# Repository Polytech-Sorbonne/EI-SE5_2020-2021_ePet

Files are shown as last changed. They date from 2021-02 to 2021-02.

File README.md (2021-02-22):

# Projet IOT : ePet

Projet réalisé dans le cadre de l'UE de "Projet IOT" , réalisé par 4 élèves ingénieurs de Polytech Sorbonne. Ce sujet a été proposé par Mme CHOTIN.

Le projet consiste en un collier connecté pour animal de compagnie, permettant de suivre sa position et d'avoir des informations pertinentes de son activité, notamment sa localisation, détecter s'il est sorti du périmètre de sécurité instauré par son maître. Le collier est équipé d'une ESP32 qui récupère également la température de l'animal afin de vérifier son état de santé.

## Comment obtient-on ces différentes informations :
 - Les données sont envoyées via Sigfox à notre serveur local hébergé sur une Raspberry Pi.  
 - Les déplacements sont détectés via un accéléromètre et les températures via un thermomètre.
 - La localisation est obtenue à partir des réseaux WIFI détectés à proximité de l'ESP32. On récupère les deux réseaux WIFI avec un signal le plus puissant et on envoie les informations à l'API Google qui nous renvoie la géolocalisation de l'animal.
 - Le maître peut visualiser ces données via le site mis en place hébergé par le serveur.

## Serveur :

Pour la partie serveur, toutes les informations se trouvent dans la partie CLOUD. Il y a également un tutoriel pour configurer une box et une raspberry pi afin d'héberger un site web.

## Electronique :

Pour la partie électronique, le matériel utilisé est renseigné dans le fichier Liste_du_matériels_finale.pdf . On obtient le système ci-dessous:

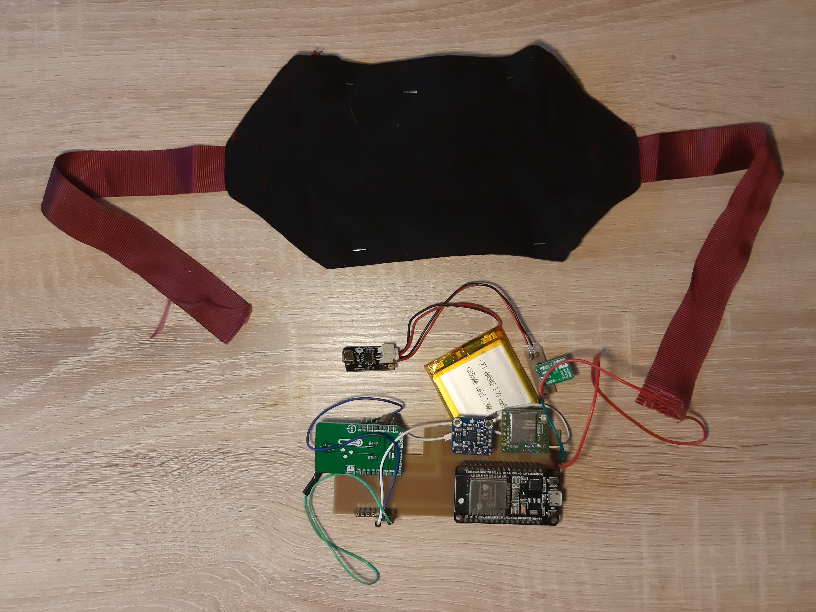
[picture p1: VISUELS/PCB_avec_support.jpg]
Electronique
    

Dans cette partie, vous trouverez également :
####
 * les codes arduino pour ESP32 (voir BLE/ et CODE/)
 * les différentes adresses MAC à exclure pour la détection des adresses MAC des WIFI
 * les schémas des PCB ainsi que les fichiers des traçages et de perçage.
 * les schémas électroniques pour effectuer les branchements des capteurs sur une plaque LABDEC  

## Fonctionnement du site :

Pour visualiser les différentes données envoyées par l'antenne Sigfox, nous avons réalisé un site. Ce site est constitué de plusieurs pages HTML.

### Identification :

Lorsque qu'un utilisateur veut consulter son compte utilisateur, il doit obligatoirement renseigner son identifiant ainsi que son mot de passe pour se connecter.

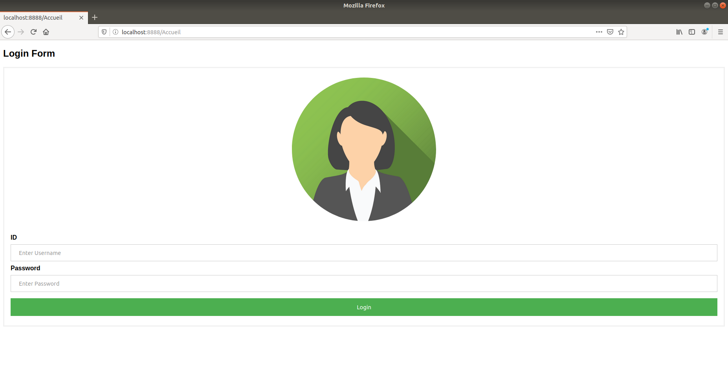
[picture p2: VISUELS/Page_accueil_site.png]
Site Identification


### Espace utilisateur :

Cet espace permet à l'utilisateur de sélectionner l'information qui veut consulter. Il peut donc accéder soit à la localisation soit à la température de ces animaux de compagnie. Il peut également consulter le code source disponible sur ce Github.

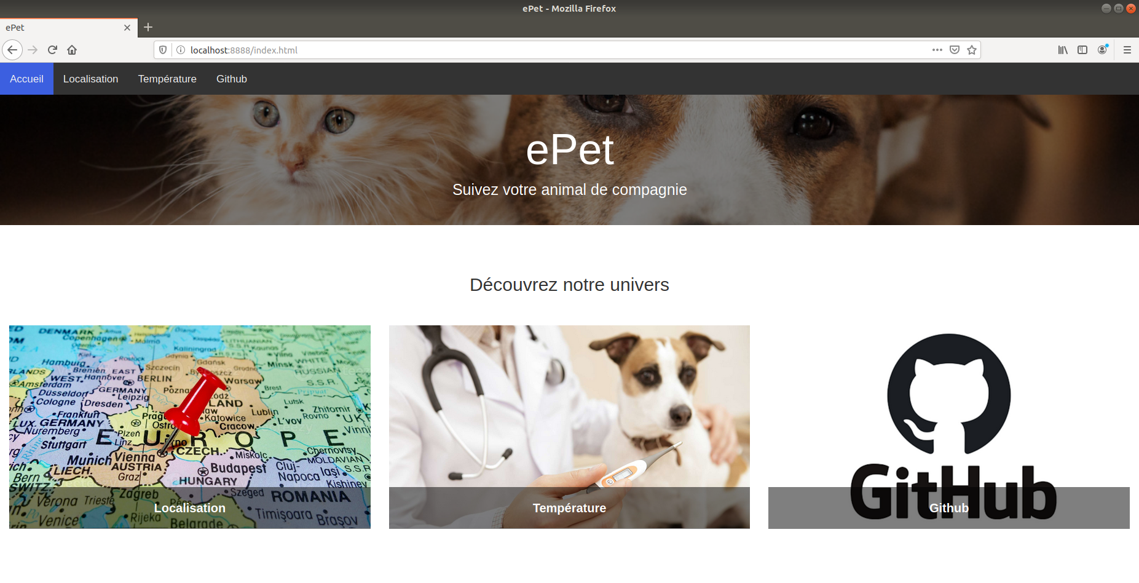
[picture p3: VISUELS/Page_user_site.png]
Site Espace Utilisateur


### Localisation :

Dans cette page, on peut choisir l'animal pour lequel on veut consulter sa position. Lorsque l'animal est en dehors du périmètre défini, un message s'affiche.

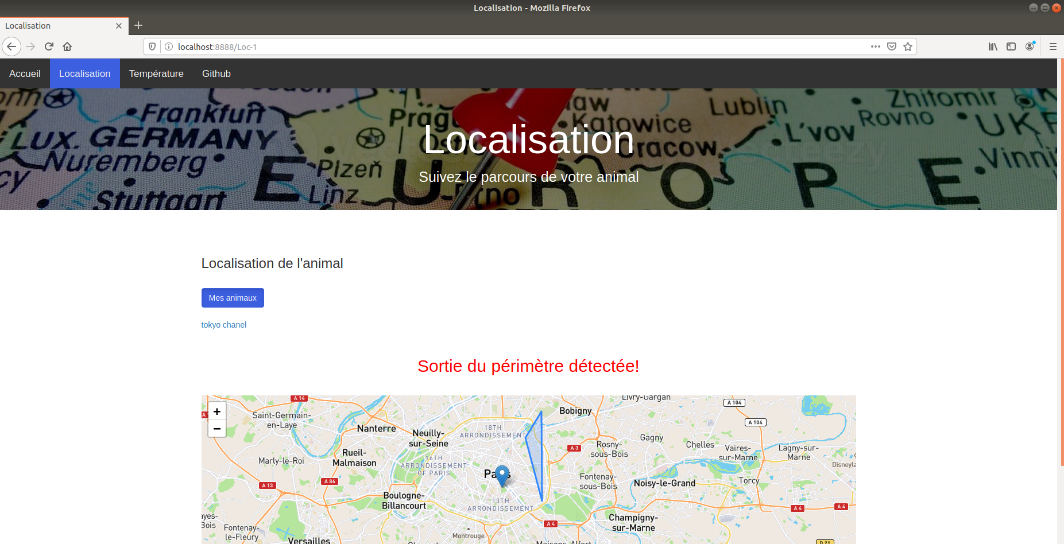
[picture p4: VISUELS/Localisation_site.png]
Site Localisation


### Température :  

Pour la température, on peut consulter la température de son animal grâce à un tableau. La température s'affiche seulement dans le cas où la température est anormale.

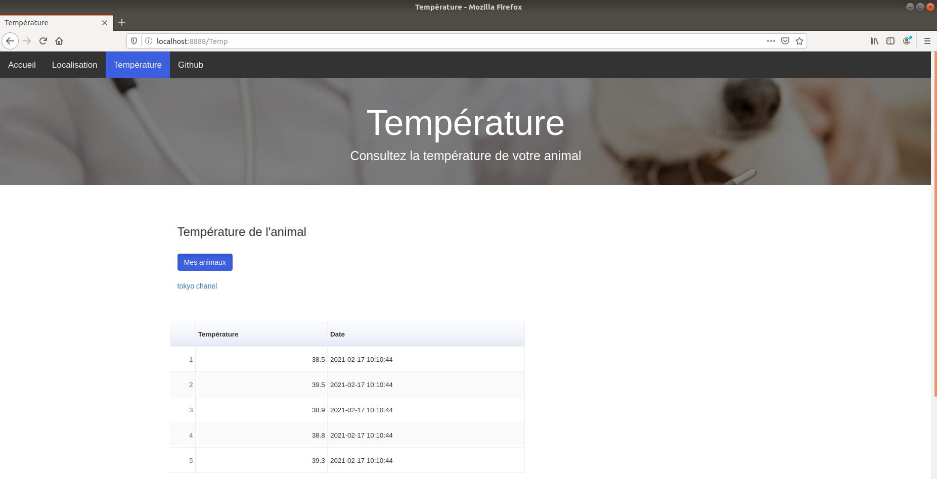
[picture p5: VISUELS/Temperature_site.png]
Site Température


### Vidéo:
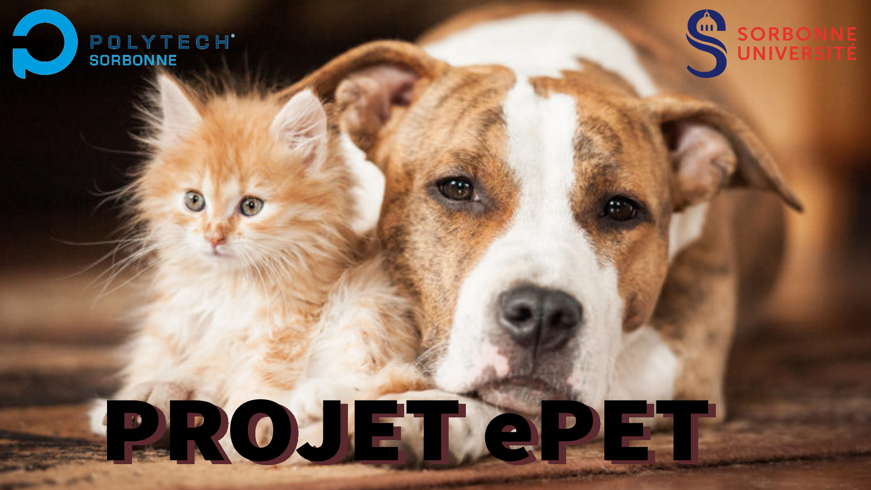
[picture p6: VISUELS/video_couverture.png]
Vidéo présentation

Consultez notre vidéo de présentation au lien suivant: https://youtu.be/6R1KARqUVJA

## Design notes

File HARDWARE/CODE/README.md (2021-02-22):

# Code Arduino 
Les dossiers contenus ici contiennent le code arduino compatible à l'esp32. Les librairies de l'accéléromètre MMA8451, et du capteur de temperature SHTC3 doivent être ajoutées aux codes correspondant et pour le schema complet. 

## Schéma complet
Explication du code:
Toutes les NB_SECOND = 60 , une interruption a lieu.
Cette interruption est rattachée à la tâche task1: elle permet de déterminer quand on doit stocker les données associées à l'accéléromètre et celles associées au capteur de température via deux compteurs : minutes_acc et totalInterruptCounter.

Au bout de 7 minutes, une moyenne des temperatures relevées est faite et stockée dans temp1 et temp2.

Pendant 15 minutes, des données d'activité sont déterminées en comparant la différence d'accélération sur les axes X et Y à un seuil de valeur seuilX et seuilY: si la différence est minime, on considère que l'activité n'est pas considérable. 

Sinon on le stocke dans mouvX ou mouvY et on incrémente un compteur countX ou countY suivant l'axe. 

Finalement, au bout de 15 minutes dans la loop principale, on scanne les wifis environnantes, on vérifie que ce ne sont pas les mêmes que l'on a déjà transmises au serveur, on élimine celles qui sont signes d'un constructeur mobile (en les comparant les 3 premiers octets avec ceux du tableau mac) et on forme le message Sigfox à envoyer au serveur. 

Ce message se forme en testant si la température est en dehors d'une plage de valeur typique d'une température normale d'un animal de compagnie (37-38 °C +- sensibilité_capteur), et si l'animal à bougé de façon significative (countX + countY > Xaddseuil + Yaddseuil). 

Ainsi, selon le cas, la trame formée et envoyée sera différente (voir doc SITE pour le décodage)

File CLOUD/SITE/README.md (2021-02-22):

# Serveur correspondant au site de visualisation des données

## Base de données
Le serveur est rattaché à une base de données epet.db, mise à jour à chaque réception de données.

## Récupération des données
Les données sont récupérées depuis le backend de sigfox via un POST sur /device.
Elles sont envoyées sous format JSON et contiennent :
- l'id du device Sigfox émetteur,
- la trame reçue
- le timestamp associé

Pour pouvoir recevoir les callbacks depuis le backend de Sigfox, il faut lancer le serveur en public. Dans le cadre de notre projet nous l'avons hébergé sur une Raspberry Pi.

Les fichiers contenus dans example_requests permettent de simuler un callback sigfox pour plusieurs trames.
	
## Localisation et requêtes Google API
La localisation est déterminée par la technique de sniffing de wifi, avec 2 adresses mac environnant le device et leur rssi, on peut interroger des bases telles que celle de Google, et recevoir une localisation. Pour se faire, il faut enregistrer un compte sur Google Api, créer un profil de paiement, et récupérer une clé API.
Notre clé API Google a été stockée dans le fichier key2.txt .

Le fichier Geoloc_example.py permet de récupérer les adresses mac et leur rssi depuis deux trames tests, puis d'interroger google API et récupérer le couple (lat,long) dans la réponse.

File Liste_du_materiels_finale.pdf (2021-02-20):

| | | | | | | Liens
Dénomination | Référence constructeur | Code commande | Quantité | Fournisseur | Lien URL | Montant TTC | Gotronic : https://www.gotronic.fr/
Module Sigfox Wisol | BRKWS01 | | 1 | | | | Farnell : https://fr.farnell.com/
Accéléromètre (I2C) | Accéléromètre 3 axes MMA8451, code : 33246 | | 1 | GoTronic | https://www.gotronic.fr/art-accelerometre-3-axes-mma8451-22164.htm 9,65 | | RS Components : https://fr.rs-online.com/web/
Microcontrôleur ESP32 | 35989 | | 1 | GoTronic | https://www.gotronic.fr/art-module-nodemcu-esp32-28407.htm 12
Batterie | Li-Ion Battery 3,7V 1050 mAh | | 1 | GoTronic | https://www.gotronic.fr/art-accu-li-ion-3-7-v-1050-mah-pr474446-5811.htm#complte_desc 10,9
Lipo Rider | Chargeur LiPo Micro-USB DFR0667, code: 36974 | | 1 | GoTronic | https://www.gotronic.fr/art-chargeur-lipo-micro-usb-dfr0667-32439.htm 6,3
Régulateur 3,3V | Régulateur 3,3 V S7V8F3 | | 1 | GoTronic | https://www.gotronic.fr/art-regulateur-3-3-v-s7v8f3-21747.htm 6,2
Capteur de température | Carte Click 9 Temp et Hum, capteur de température/humidité SHTC3 | | 1 | Farnell | https://fr.farnell.com/mikroelektronika/mikroe-3331/carte-click-temperature-humidite/dp/3013737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 12,74
| | | | | Total | 57,79

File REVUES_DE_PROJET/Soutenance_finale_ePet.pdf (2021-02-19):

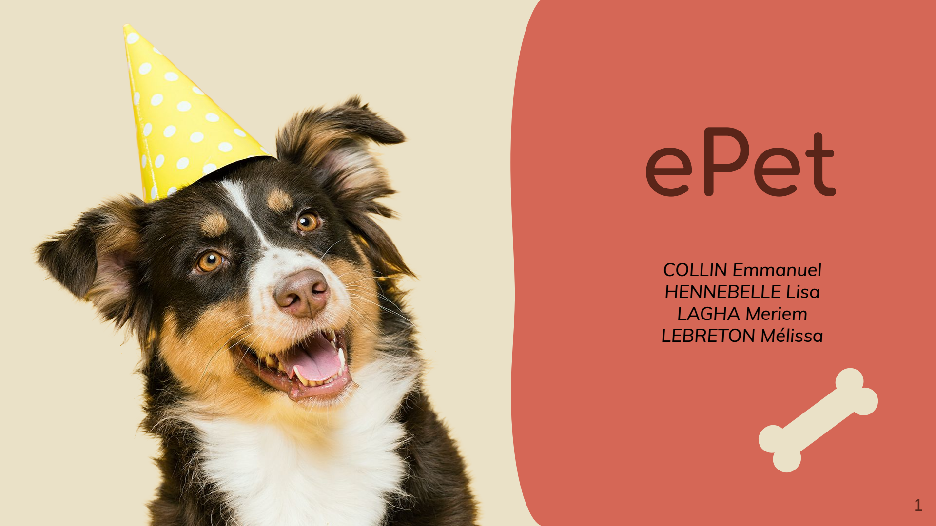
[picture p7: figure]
ePet; COLLIN Emmanuel HENNEBELLE Lisa LAGHA Meriem LEBRETON Mélissa

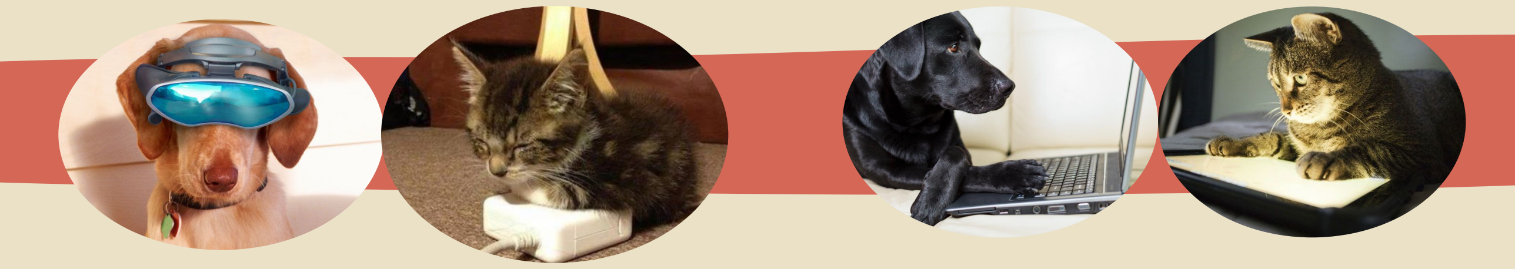
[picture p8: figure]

COLLIN Emmanuel, HENNEBELLE Lisa, LAGHA Meriem, LEBRETON Mélissa - Projet IoT : ePet

# Présentation de l’équipe et des rôles

## Lisa -Equipe Hardware-

## Emmanuel -Equipe Software-

## Meriem -Equipe Software-

## Mélissa -Equipe Hardware-

# Contexte

# Applications existantes :

# Incomplètes

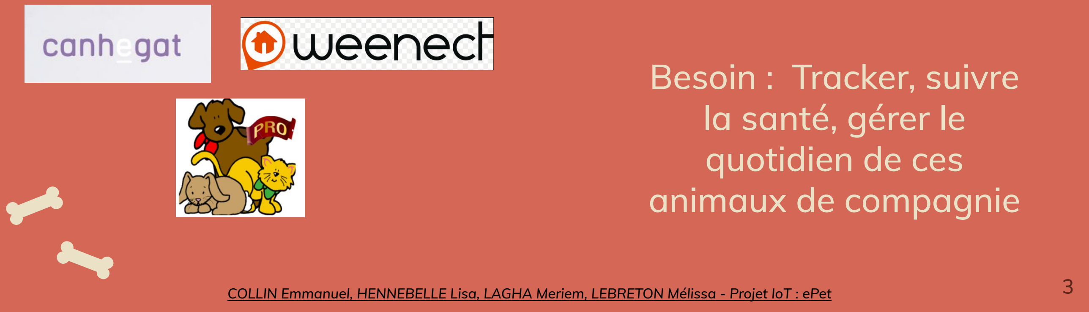
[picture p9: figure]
Besoin : Tracker, suivre la santé, gérer le quotidien de ces animaux de compagnie

# Table oÿ Contents

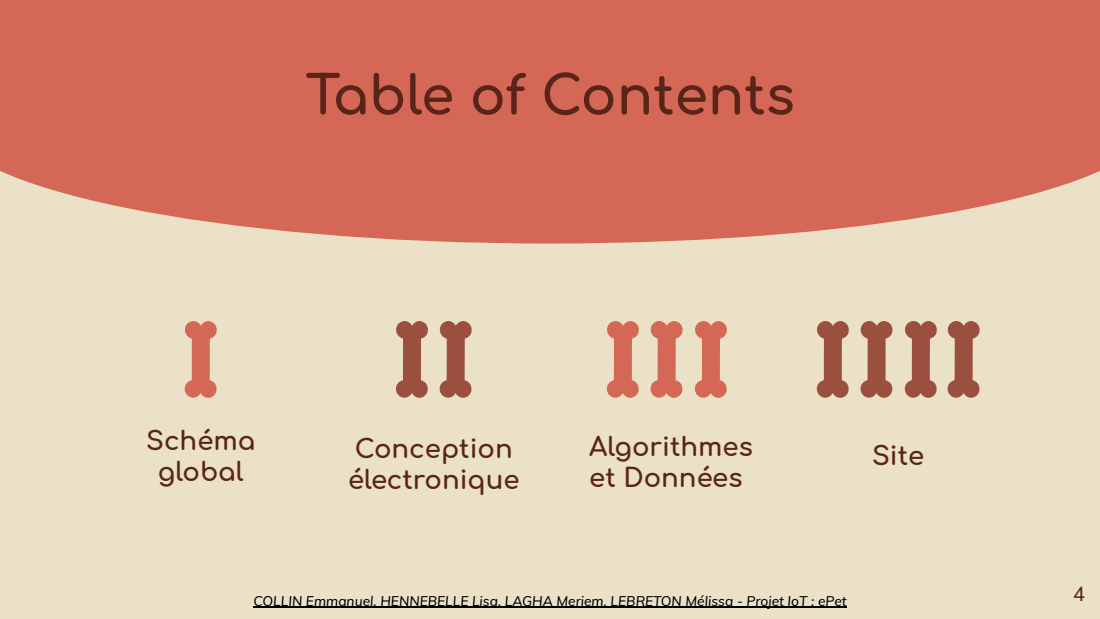
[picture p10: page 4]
Conception électronique; Alorithmes et Données; Schéma; lobal; Site

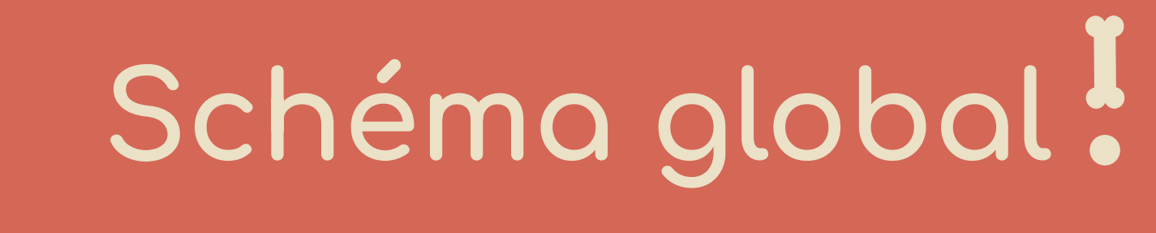
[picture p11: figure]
Schéma lobal

HARDWARE | SOFTWARE

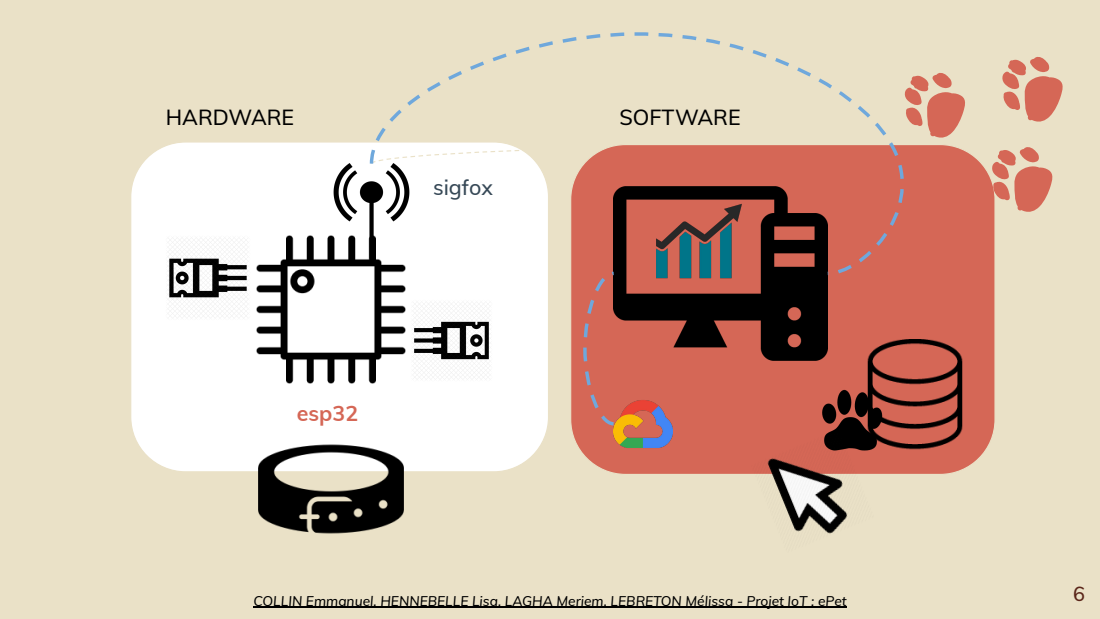
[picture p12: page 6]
esp32; sigfox

# Conception

# électronique

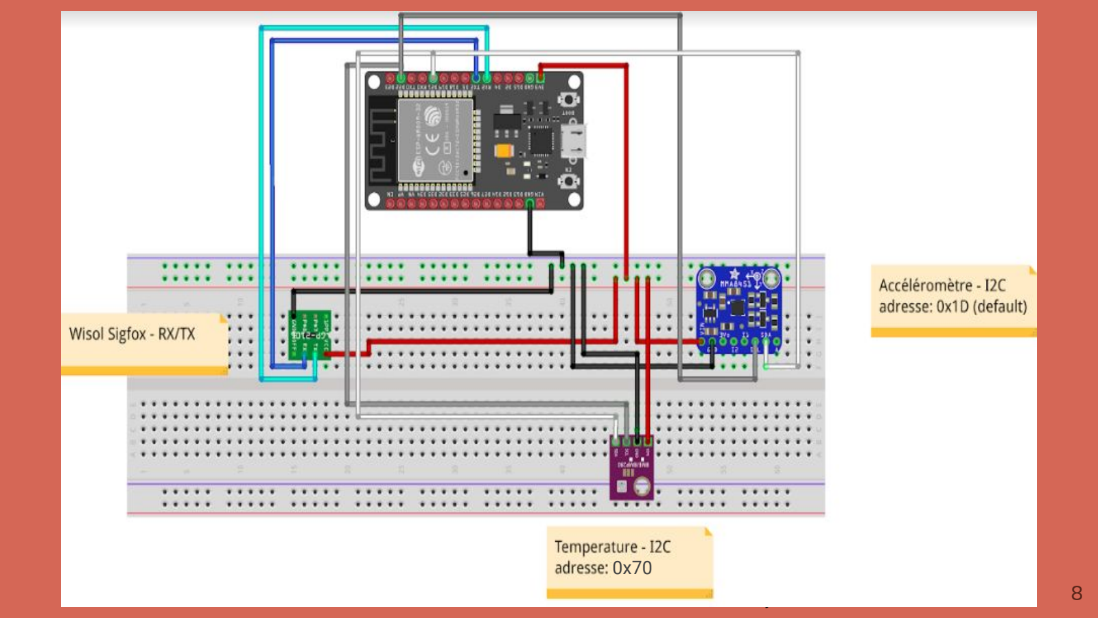
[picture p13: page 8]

0x70

# PCB d’alimentation

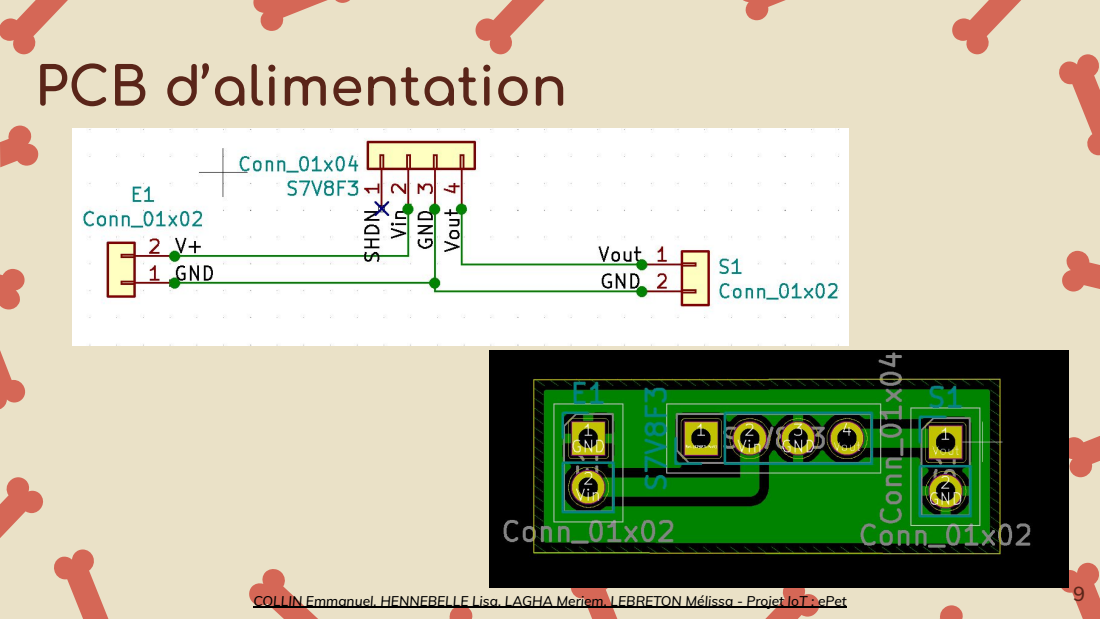
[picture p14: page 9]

# PCB des capteurs

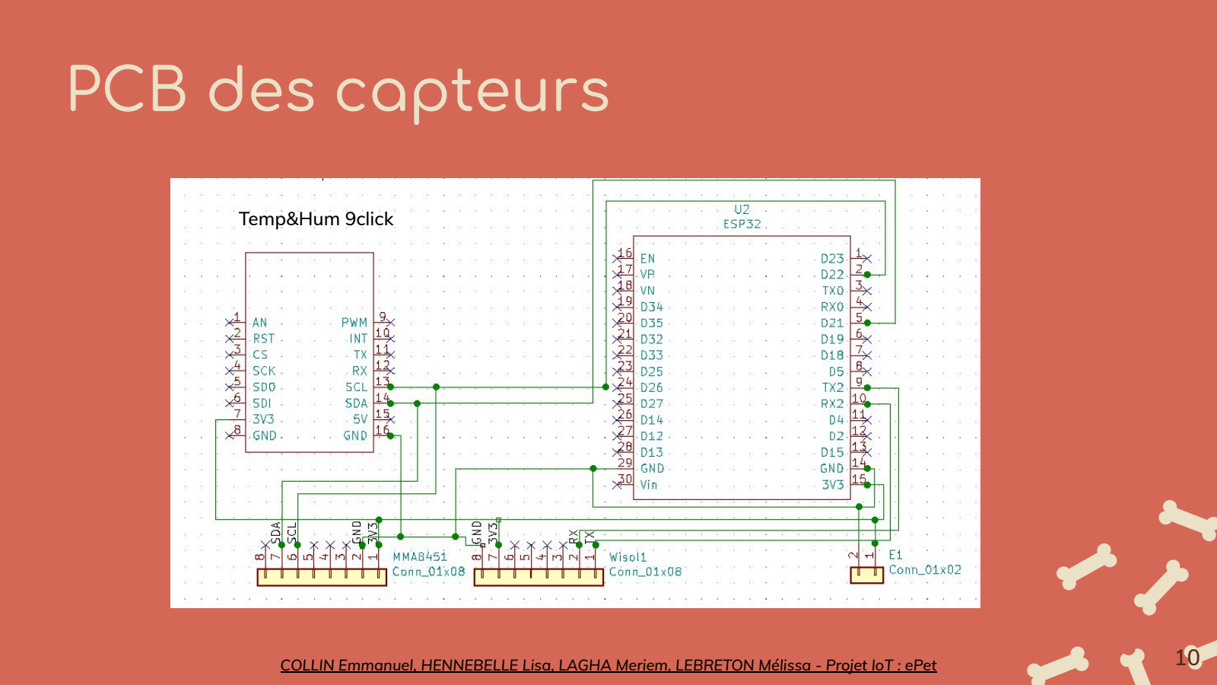
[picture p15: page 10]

COLLIN Emmanuel, HENNEBELLE Lisa, LAGHA Meriem, LEBRETON Mélissa - Projet IoT : ePet | 10

### Temp&Hum 9click

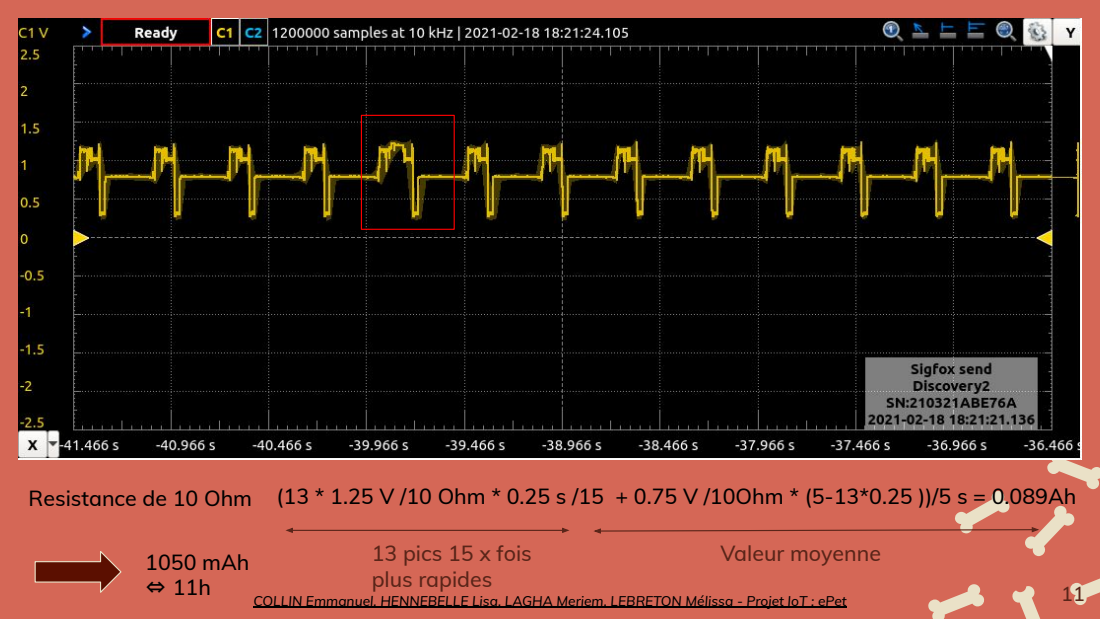
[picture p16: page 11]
COLLIN Emmanuel, HENNEBELLE Lisa, LAGHA Meriem, LEBRETON Mélissa - Projet IoT : ePet; Resistance de 10 Ohm; (13 * 1.25 V /10 Ohm * 0.25 s /15 + 0.75 V /10Ohm * (5-13*0.25 ))/5 s = 0.089Ah; 13 pics 15 x fois plus rapides

Valeur moyenne 1050 mAh

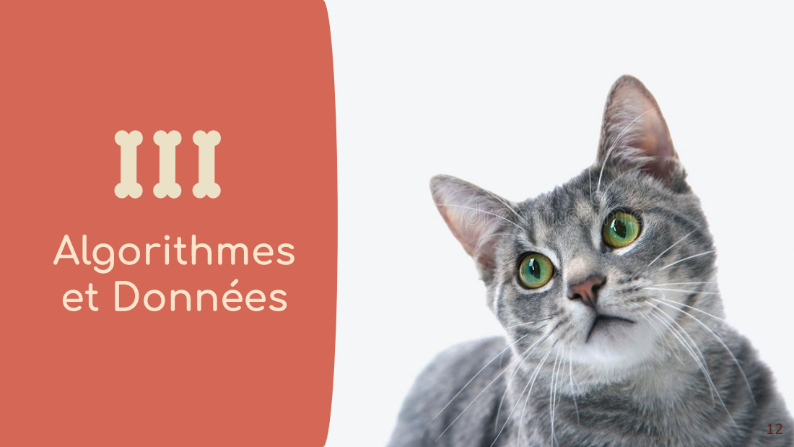
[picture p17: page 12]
Alorithmes et Données

# Algorithme

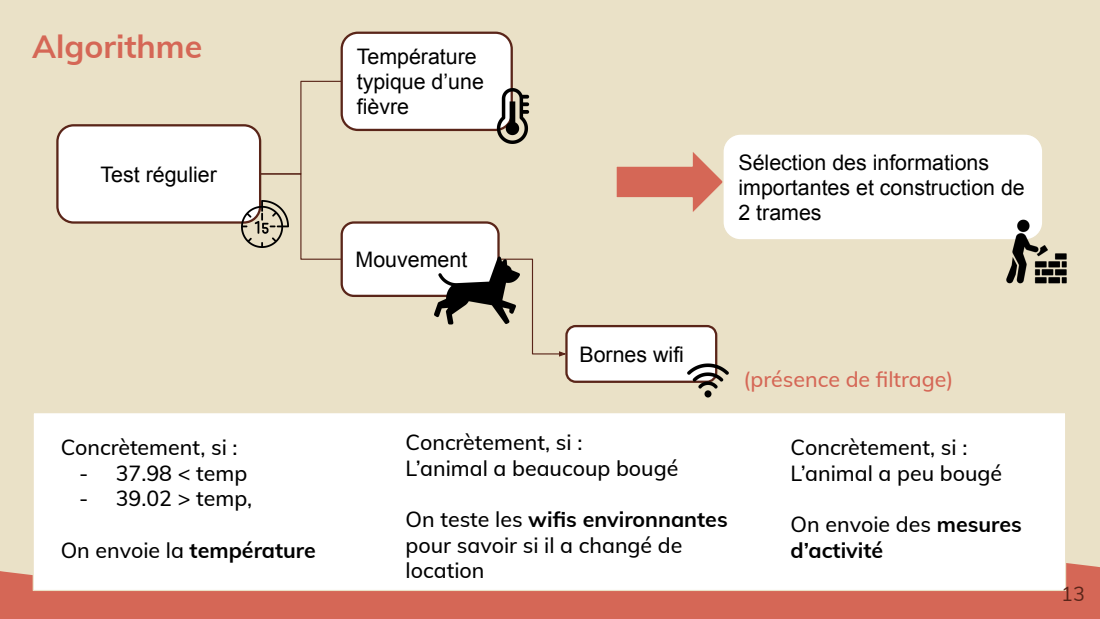
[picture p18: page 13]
Test régulier; Température typique d’une fièvre; Mouvement; Concrètement, si : - 37.98 < temp - 39.02 > temp,; Bornes wifi

Sélection des informations
importantes et construction de
2 trames

(présence de filtrage)

Concrètement, si :
L’animal a beaucoup bougé

L’animal a peu bougé

On teste les wifis environnantes
pour savoir si il a changé de
location

On envoie des mesures
d’activité

On envoie la température

XX | 0X
6 octets | 1 octet | 2 octets | 2 octets

trame de 10 octets (10*8 bits) maximum
| RSSI
| | XX | XX
XX | | XX | | XX | XX | XX | XX | XX

(puissance
du signal) BSSID (@ MAC) ou mouvX ou mouvY | temp (°C)

XX

1 octet

loc_mode

Tempér ature | mouvement X & Y | BSSID + RSSI | valeur de loc_mode associé
Cas 0 | NON | NON | - | Pas d’envoi
Cas 1 | OUI | NON | - | 06
Cas 2 | NON | OUI | NON | 01(X) ou 02(Y)
Cas 3 | OUI | OUI | NON | 04(X) ou 05(Y)
Cas 4 | NON | OUI | OUI | 00
Cas 5 | OUI | OUI | OUI

# Callback Sigfox

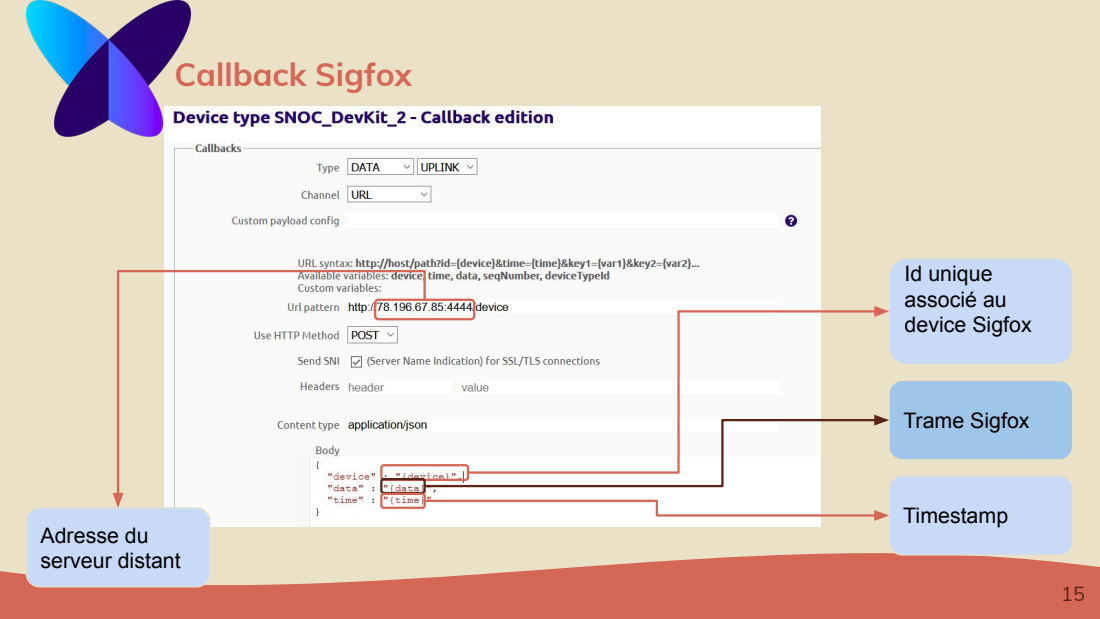
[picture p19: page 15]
Adresse du serveur distant; Id unique associé au device Sigfox; Trame Sigfox; Timestamp

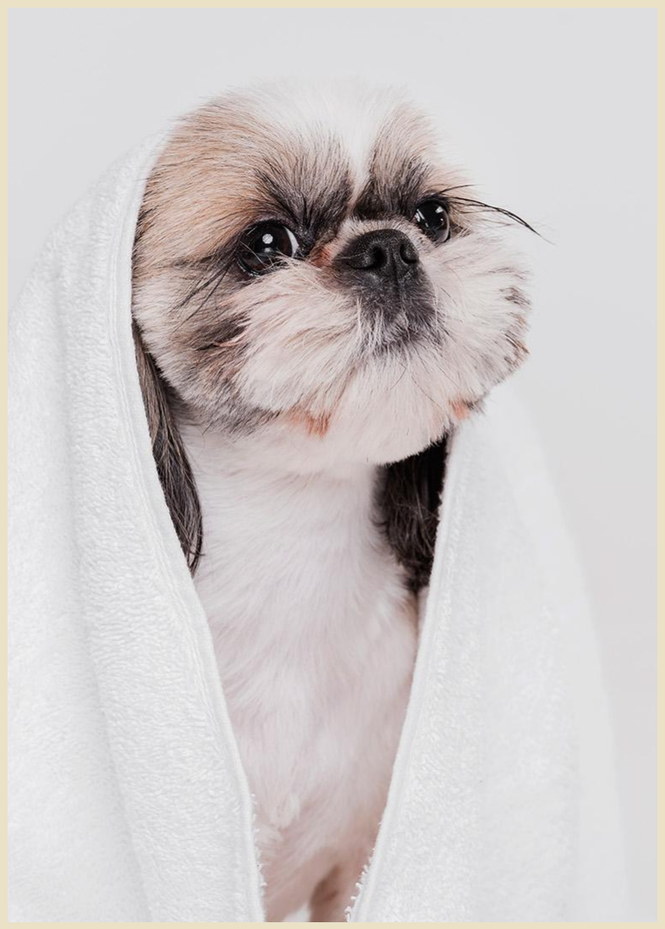
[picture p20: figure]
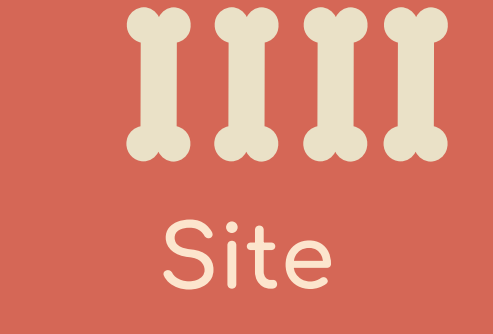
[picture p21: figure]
Site
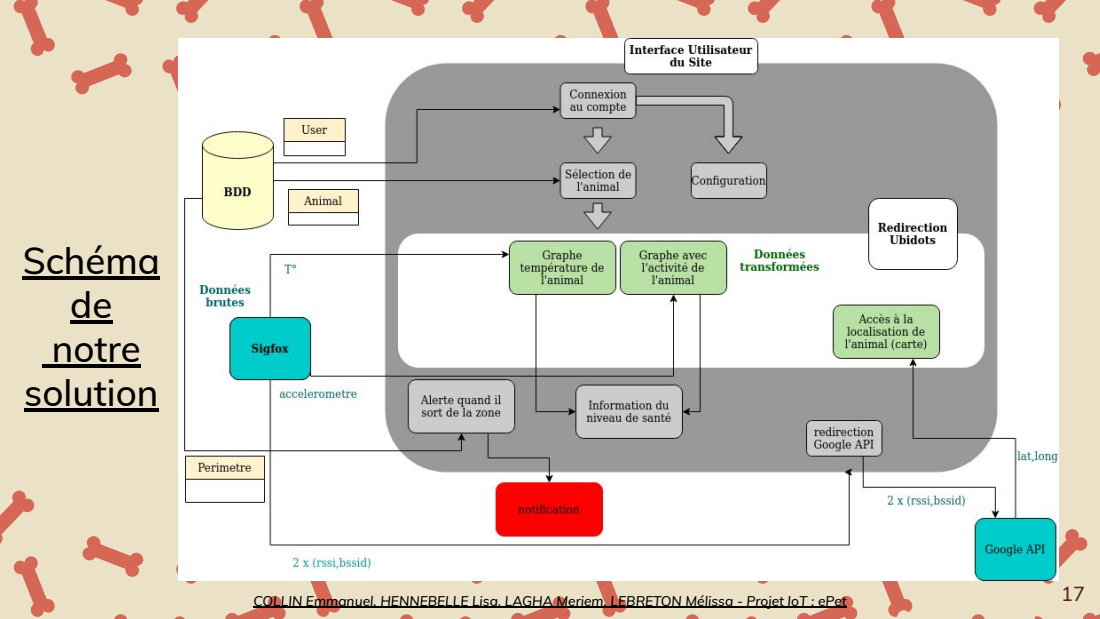
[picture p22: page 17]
Schéma de notre solution

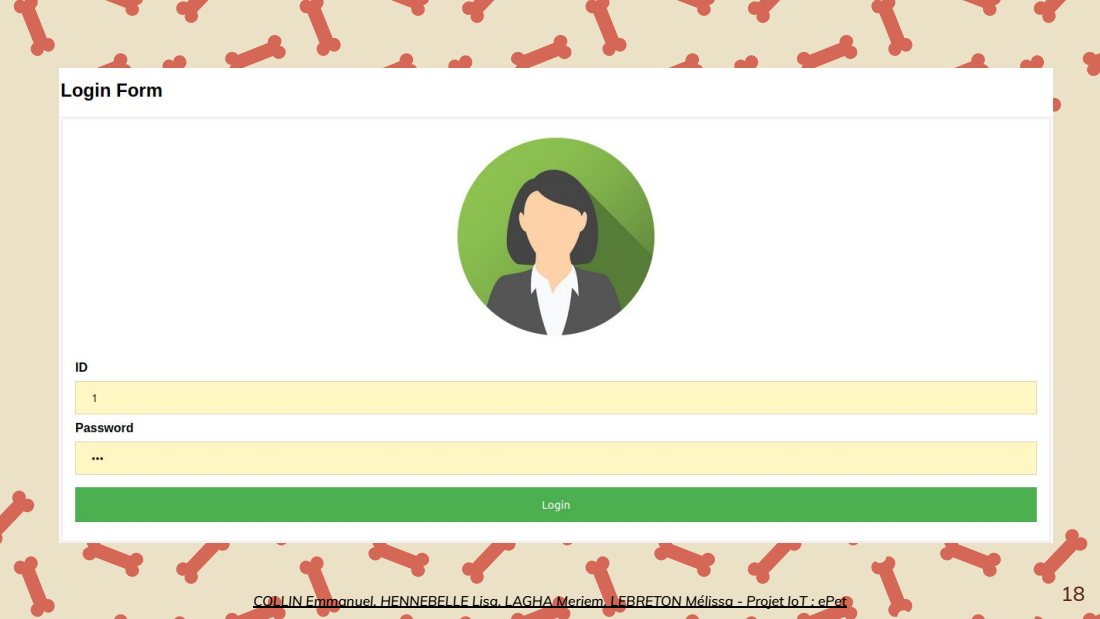
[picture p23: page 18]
COLLIN Emmanuel, HENNEBELLE Lisa, LAGHA Meriem, LEBRETON Mélissa - Projet IoT : ePet

# Tentative de connexion qui échoue

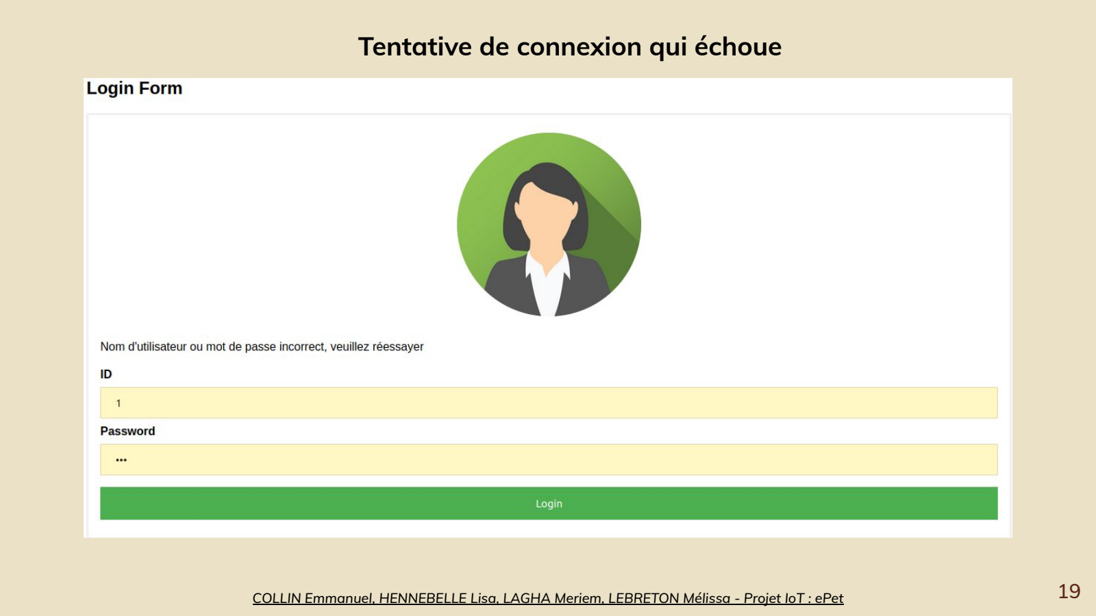
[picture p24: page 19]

COLLIN Emmanuel, HENNEBELLE Lisa, LAGHA Meriem, LEBRETON Mélissa - Projet IoT : ePet | 19

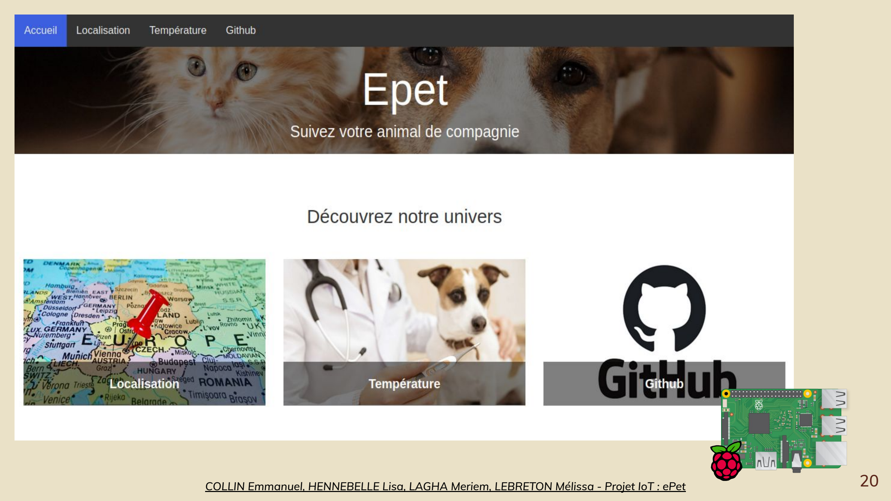
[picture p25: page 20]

4 5

# Ajout de filtres pour la sélection de l’animal

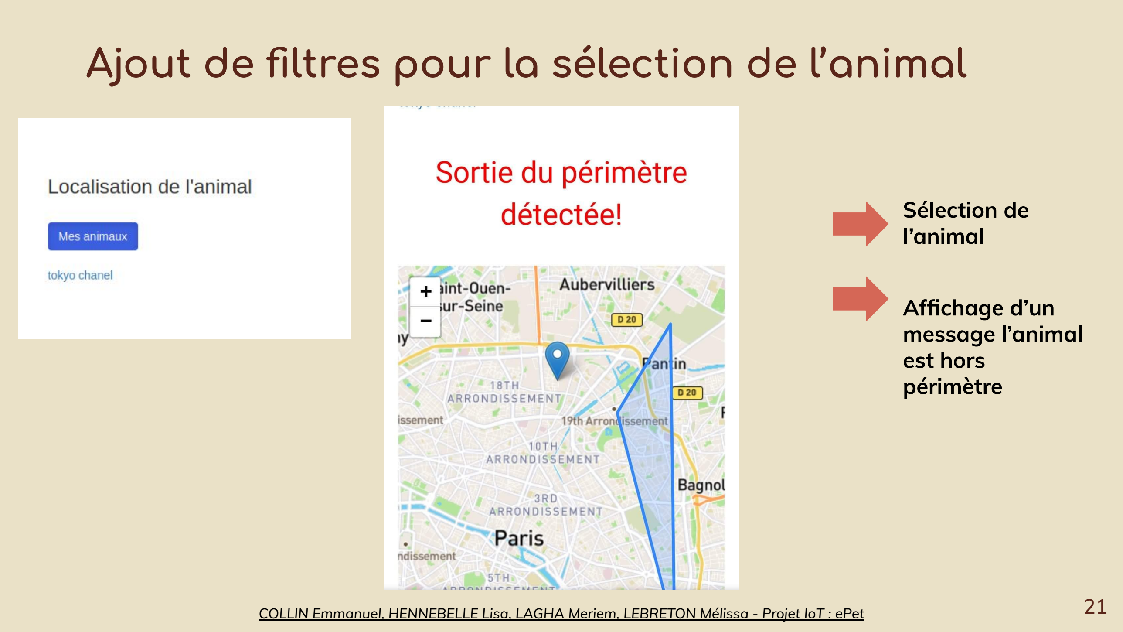
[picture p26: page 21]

## Sélection de l’animal

## Affichage d’un message l’animal est hors périmètre

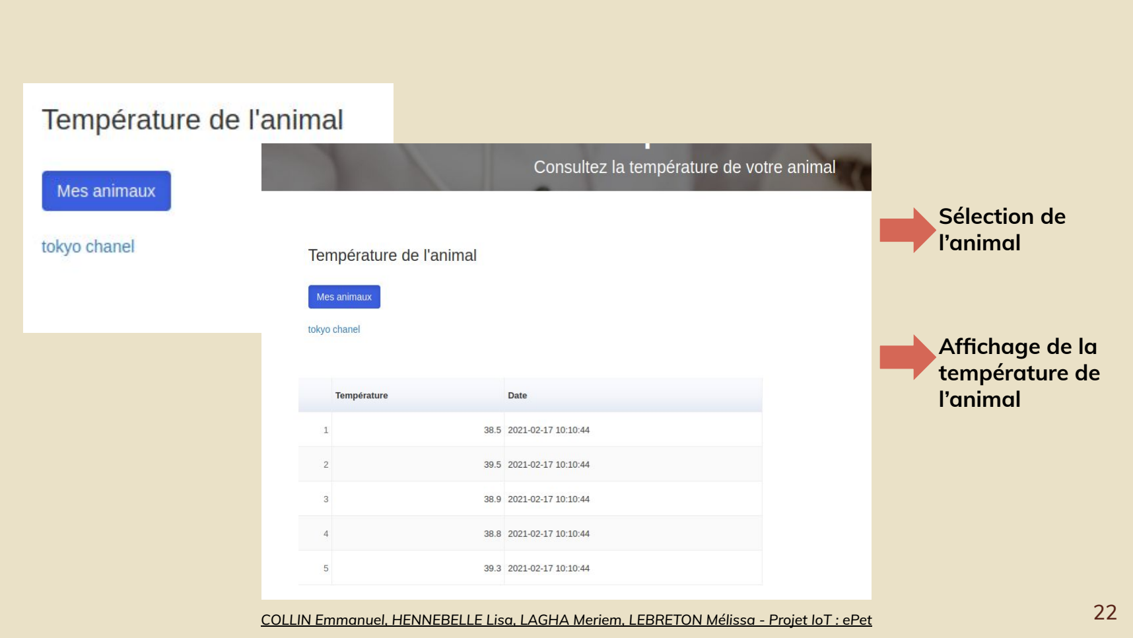
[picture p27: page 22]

COLLIN Emmanuel, HENNEBELLE Lisa, LAGHA Meriem, LEBRETON Mélissa - Projet IoT : ePet | 22

## Sélection de l’animal

## Affichage de la température de l’animal

HARDWARE | SOFTWARE

# Avancement

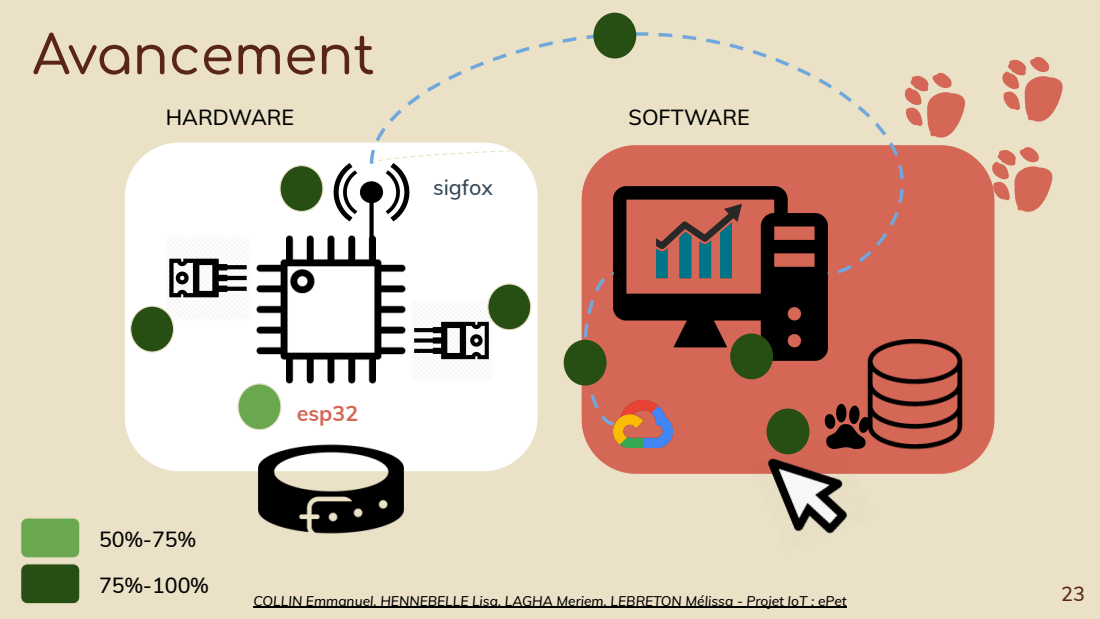
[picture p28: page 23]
esp32; sigfox

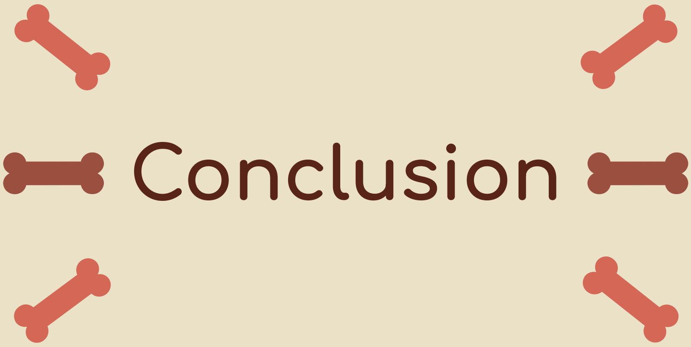
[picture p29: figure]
CREDITS: This presentation template was; and infographics & images by Freepik.; Conclusion

created by Slidesgo, (http://bit.ly/2Tynxth) including icons by Flaticon, (http://bit.ly/2TyoMsr)

COLLIN Emmanuel, HENNEBELLE Lisa, LAGHA Meriem, LEBRETON Mélissa - Projet IoT : ePet | 24

## Compétences hardware/software/IOT

# Projet complet

# Division du travail

## Equipes de 2 Hardware/Software

# Étendues du projet

A suivre...

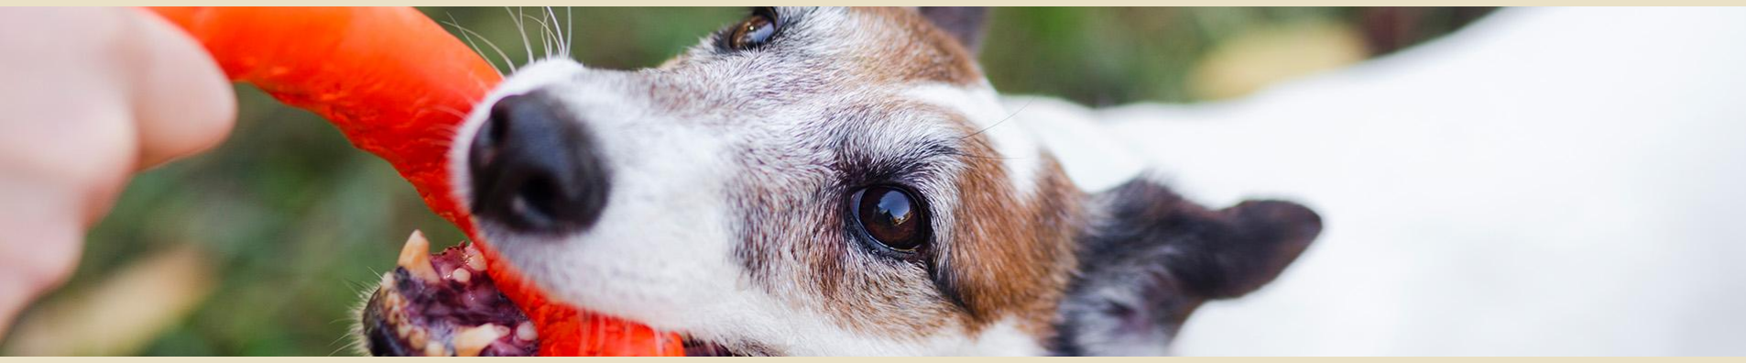
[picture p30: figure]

# 1 Merci pour votre attention!

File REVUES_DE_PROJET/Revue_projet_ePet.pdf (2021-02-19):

ePet; COLLIN Emmanuel HENNEBELLE Lisa LAGHA Meriem LEBRETON Mélissa

# Table oÿ Contents

Schéma électronique et site; Données Schéma; lobal; Site

COLLIN Emmanuel, HENNEBELLE Lisa, LAGHA Meriem, LEBRETON Mélissa - Projet IoT : ePet

Schéma lobal

HARDWARE | SOFTWARE

esp32; sigfox

# Schéma

# électronique et site


0x70

Schéma de notre solution


# Données

COLLIN Emmanuel, HENNEBELLE Lisa, LAGHA Meriem, LEBRETON Mélissa - Projet IoT : ePet

Site

4 5

HARDWARE | SOFTWARE

esp32; sigfox


# 1 Merci pour votre attention!

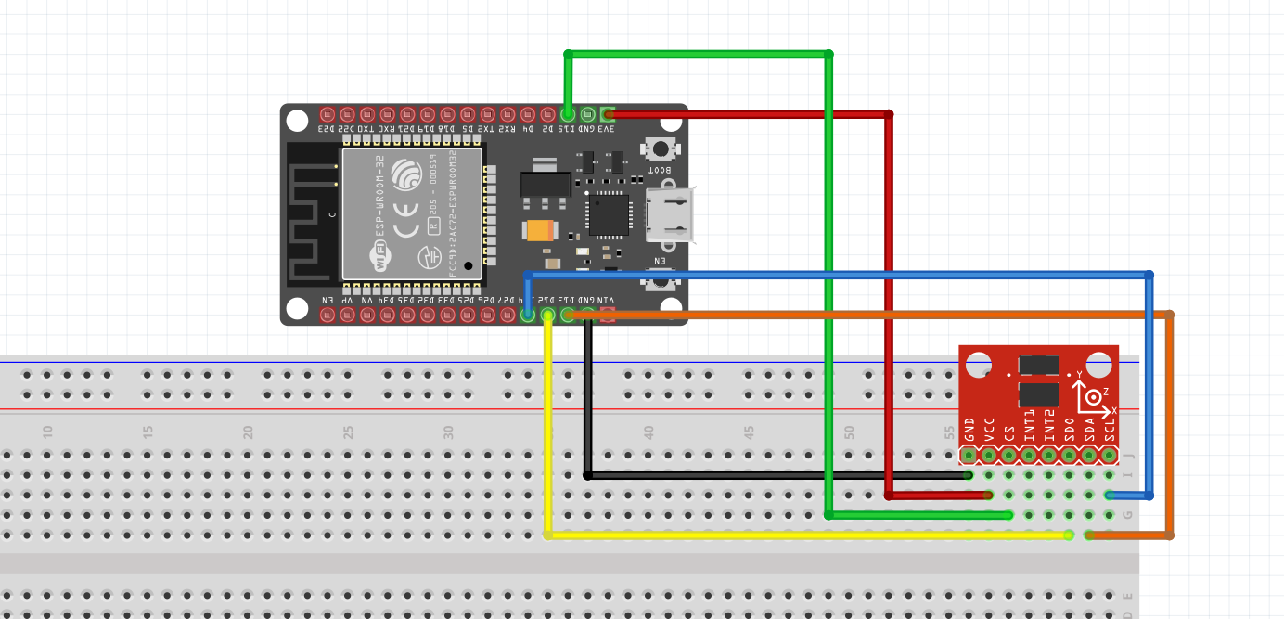
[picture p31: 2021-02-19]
HARDWARE/SCHEMAS_ELECTRONIQUES/ACCELEROMETRE/schema_branchement_accelerometre.png

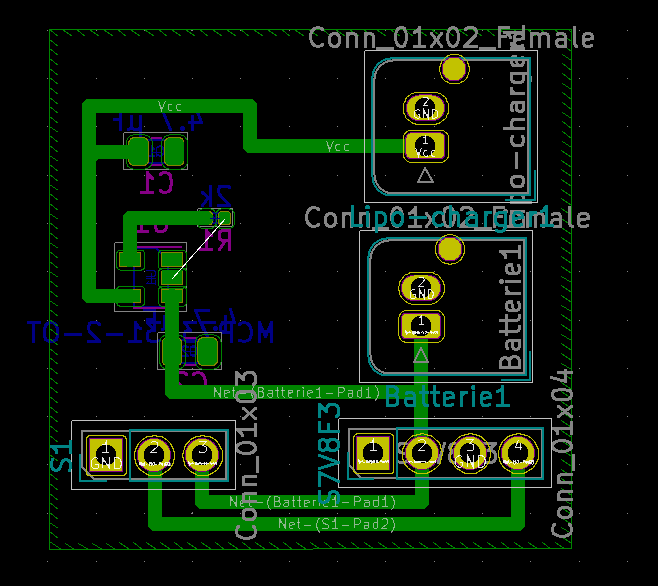
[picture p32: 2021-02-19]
HARDWARE/PCB/ALIMENTATION/PCB_alim.PNG

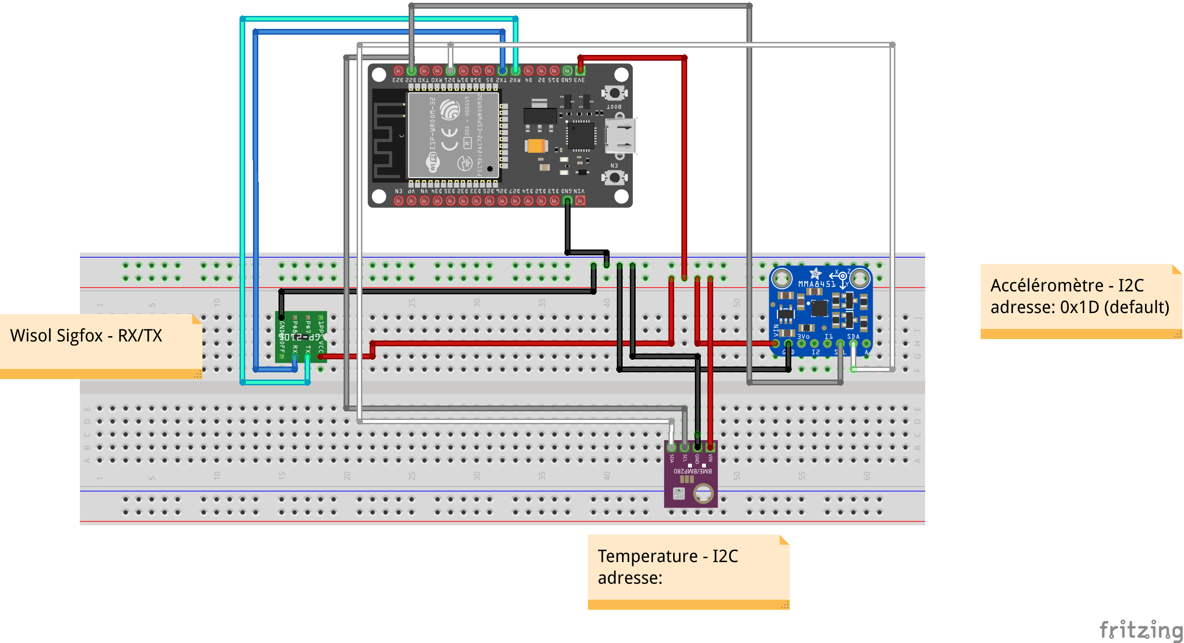
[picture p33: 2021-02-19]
HARDWARE/SCHEMAS_ELECTRONIQUES/SCHEMA_COMPLET/schéma électronique complet_bb.png

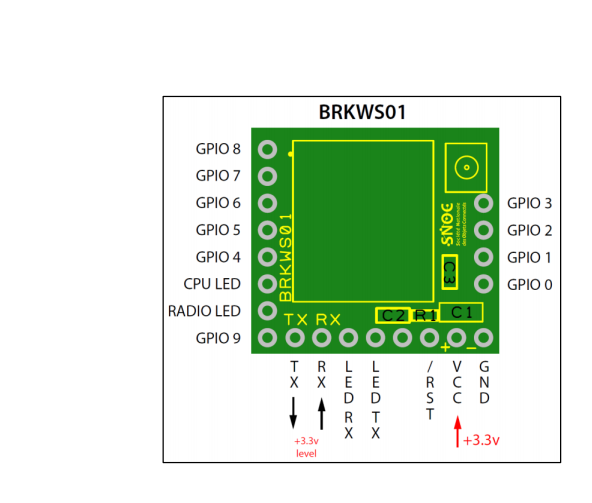
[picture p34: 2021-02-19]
HARDWARE/SCHEMAS_ELECTRONIQUES/SIGFOX/wisol.png

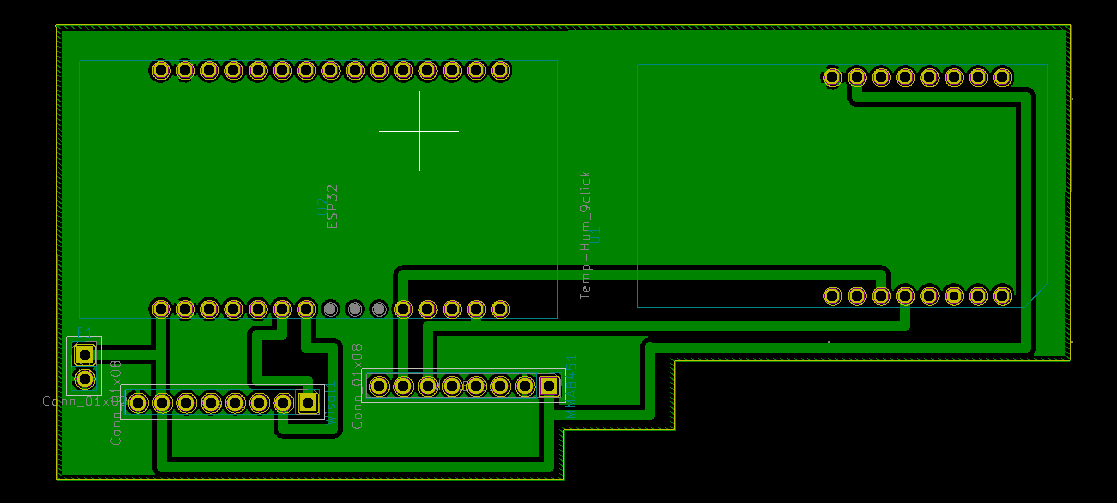
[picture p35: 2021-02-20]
HARDWARE/PCB/CAPTEURS/PCB_capteurs.PNG

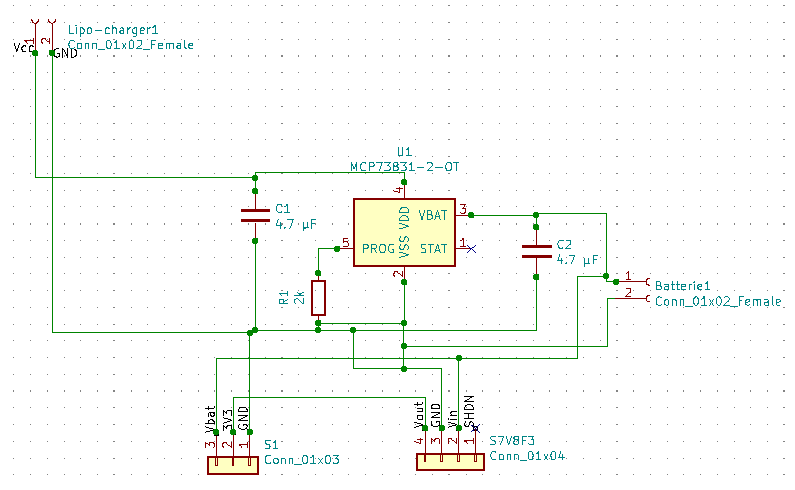
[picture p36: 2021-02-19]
HARDWARE/PCB/ALIMENTATION/Schema_pcb_alim.PNG

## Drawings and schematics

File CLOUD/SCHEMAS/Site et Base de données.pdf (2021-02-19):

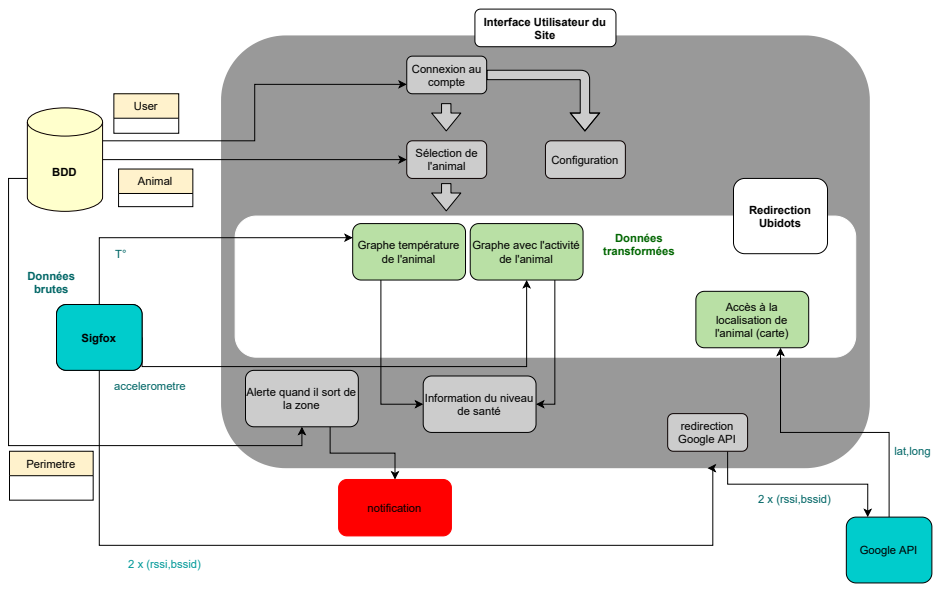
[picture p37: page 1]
Sélection de l'animal; Graphe température de l'animal; Accès à la localisation de l'animal (carte); Données transformées; BDD; Connexion au compte; notification; Site; User; Animal; Perimetre; Redirection Ubidots; Sigfox; Données brutes; 2 x (rssi,bssid); accelerometre; redirection Google API; Google API; lat,long; Configuration

Interface Utilisateur du

Graphe avec l'activité
de l'animal

Alerte quand il sort de
la zone

Information du niveau
de santé

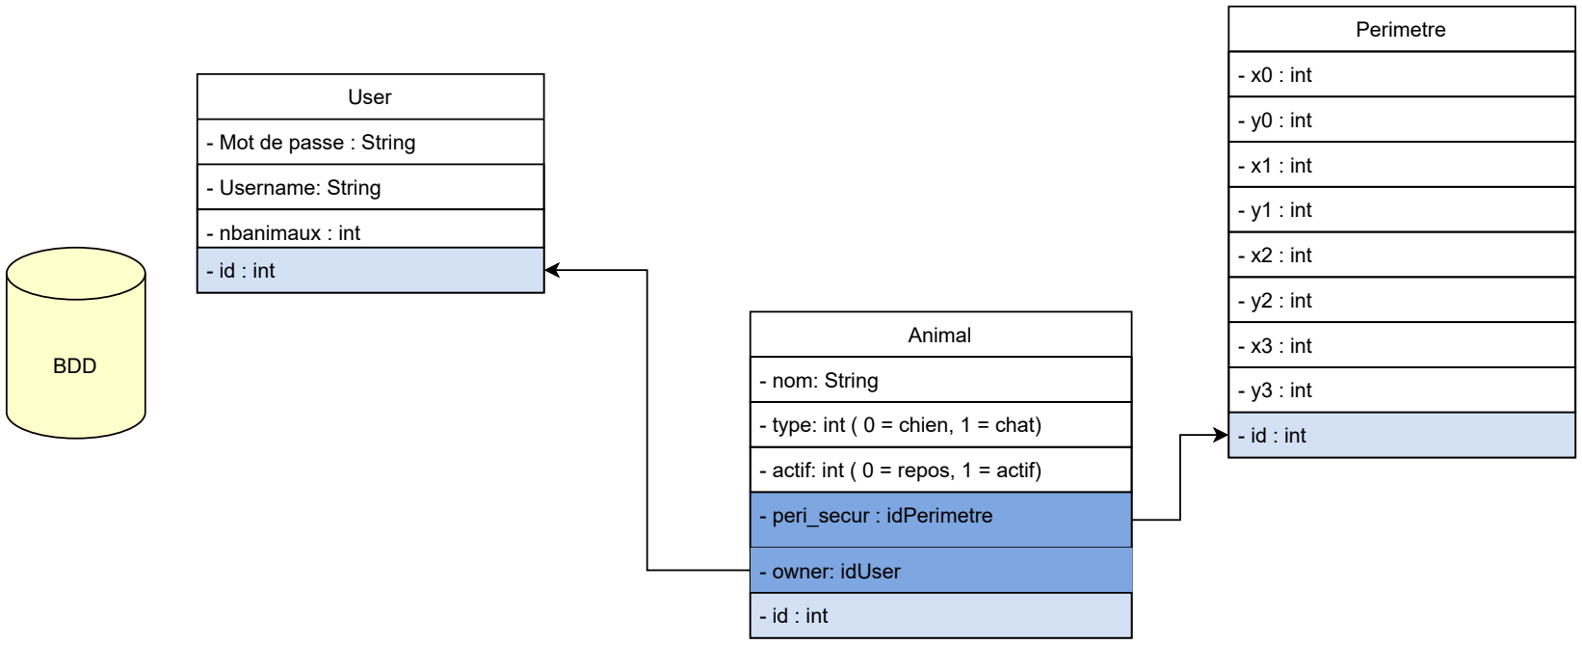
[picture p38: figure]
BDD; User; - Mot de passe : String; - Username: String; - nbanimaux : int; - id : int; Animal; - nom: String; - type: int ( 0 = chien, 1 = chat); - actif: int ( 0 = repos, 1 = actif); - peri_secur : idPerimetre; - owner: idUser; Perimetre; - x0 : int; - y0 : int; - x1 : int; - y1 : int; - x2 : int; - y2 : int; - x3 : int; - y3 : int

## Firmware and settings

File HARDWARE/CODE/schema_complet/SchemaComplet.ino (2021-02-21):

// ############################ Librairies ############################

// Librairies Accéléromètre
#include <Wire.h>
#include <Adafruit_MMA8451.h>
#include <Adafruit_Sensor.h>

// Librairies Réseaux Wifi
#include "WiFi.h"
#include <HardwareSerial.h>

//Librairies Température
#include "Adafruit_SHTC3.h"


// ############################ Macros ############################

#define DEBUG true
#define RX0 16 // PIN RX0 <=> D3
#define TX0 17 // PIN TX0 <=> D1
#define NB_SECOND 60/15 // 1 min
#define DELAY_TASK 60000 / 15

//Accelerometre
#define SEUILX 0.75
#define SEUILY 0.75

//seuils sur X et Y accumulés pendant 15 minutes_acc
#define Xaddseuil 5
#define Yaddseuil 5

// ############################ Variables ############################

Adafruit_MMA8451 mma = Adafruit_MMA8451();

// Message SigFox
byte bssid1_prec[6], bssid2_prec[6], bssid1[6], bssid2[6];
byte rssi1, rssi2; 

// Température
int t, temp1, temp2;
//tableaux des températures sur 15 minutes_acc
int temp_tab[7];

hw_timer_t * timer;
volatile int interruptCounter;
volatile int minutes_acc;
int totalInterruptCounter;
sensors_event_t humidity, temp;
sensors_event_t event;

double x_0;
double x_1;
double y_0;
double y_1;

double diffX = 0;
double diffY = 0;
int countX = 0 ,countY = 0;
int countmintX = 0, countmintY = 0;
int addedcountX = 0, addedcountY = 0; 

//tableaux des mouvements sur les deux axes sur 15 minutes_acc 
int mouvX[15];
int mouvY[15];

String status = "";
char output;

char *mac[] = {
  "9424E1","A09D86","C8F86D","00118B","00E0B1","00E0DA","DC0856","54E3F6","1880F5","000F62","184A6F","84A783","F83094","68597F","0025BA","00153F","002032","00C0BE","2CFAA2","E8E732",
  "A8AD3D","24AF4A","7C2064","D099D5","9067F3","18422F","0017CC","008039","3C28A6","0CB5DE","002060","54A619","002105","D4224E","94AE61","4C5FD2","4CA74B","54055F","9067B5","001D4C",
  "00A081","008021","6854ED","3C8BCD","00164D","001AF0","AC9CE4","00233E","6CBEE9","0021AE","001C8E","00113F","00089A","00D095","0020DA","000772","E03005","0CA402","A0F3E4","E4A1E6",
  "F4C613","885C47","040A83","002135","000E86","DC446D","608B0E","88B291","C42AD0","CCD281","1040F3","586B14","BCB863","44E66E","C0E862","F40616","E4B2FB","4C569D","38539C","402619",
  "6CE85C","F83880","1094BB","F86FC1","28FF3C","F099B6","88E9FE","38892C","749EAF","94BF2D","40CBC0","C4618B","08E689","DC56E7","5433CB","3408BC","1C36BB","3C2EFF","24F677","B0CA68",
  "C83C85","B8634D","A4E975","3035AD","844167","9800C6","AC1F74","A85C2C","00DB70","245BA7","70F087","B0702D","6C19C0","2C3361","ECADB8","9801A7","24F094","086D41","E0C767","80ED2C",
  "AC61EA","38B54D","1C5CF2","28ED6A","A4D18C","241EEB","CC25EF","28CFE9","00A040","3CD0F8","680927","6CC26B","44D884","002608","0026B0","0026BB","D49A20","F81EDF","C82A14","3C0754",
  "A4B197","F0B479","1093E9","442A60","A4D1D2","28CFDA","003065","001451","001E52","0021E9","CC08E0","045453","F4F951","C06394","18AF8F","C8B5B7","90B21F","30F7C5","40B395","44FB42",
  "E88D28","949426","207D74","F4F15A","C86F1D","3090AB","8C2DAA","848506","98FE94","D8004D","64200C","C8334B","64E682","B8E856","D89695","1499E2","B418D1","9C207B","B065BD","542696",
  "64A3CB","903C92","D81D72","341298","70E72C","70ECE4","68AE20","AC87A3","D8BB2C","D04F7E","2078F0","E0ACCB","A0999B","24240E","F0DBF8","48746E","54AE27","FCE998","0CBC9F","34363B",
  "D0A637","789F70","9CF387","A85B78","C8F650","A88E24","CC20E8","70480F","F0B0E7","0469F8","4070F5","B035B5","800C67","90812A","B87BC5","102959","E47684","F05CD5","70EA5A","B440A4",
  "48B8A3","F4DBE3","E8854B","28EC95","E02B96","FC66CF","AC1D06","44A8FC","F81093","B456E3","4C20B8","1488E6","B485E1","0C19F8","501FC6","540910","9CFC28","CC69FA","10CEE9","FC4EA4",
  "F4BEEC","54E61B","F887F1","305714","C8B1CD","1460CB","B8F12A","804A14","703C69","14C213","A4D931","BCFED9","808223","BCE143","647033","846878","C8D083","6030D4","F895EA","18F1D8",
  "30D9D9","D0817A","98CA33","68AB1E","70EF00","0C1539","D88F76","409C28","58E28F","787B8A","503237","B0481A","B49CDF","48BF6B","9C84BF","00B362","E4E4AB","60334B","FCD848","A860B6",
  "C4B301","E05F45","483B38","1C9148","30636B","A4F1E8","440010","0056CD","00CDFE","E498D6","F431C3","64A5C3","002332","00236C","0023DF","002500","0025BC","0019E3","001B63","001EC2",
  "001FF3","0010FA","0050E4","000D93","7CFADF","78A3E4","148FC6","286AB8","28E02C","E0B9BA","00C610","B8F6B1","8CFABA","7CD1C3","F0DCE2","24AB81","E0F847","28E7CF","E4CE8F","A82066",
  "BC52B7","5C5948","C8BCC8","E8040B","145A05","1CABA7","C0847A","34159E","58B035","DC86D8","90B931","D0E140","24A2E1","80EA96","600308","04F13E","98F0AB","7831C1","783A84","5C8D4E",
  "8863DF","881FA1","C8E0EB","98B8E3","885395","786C1C","4C8D79","1CE62B","0C3021","0C3E9F","FCFC48","9C293F","087402","94F6A3","98E0D9","CC29F5","285AEB","F02475","2C1F23","549F13",
  "F0DBE2","748114","18F643","A45E60","A01828","D0034B","10417F","A8667F","D02598","80BE05","24A074","84788B","587F57","006D52","B844D9","14876A","E0B55F","F8FFC2","E0EB40","3CBF60",
  "AC15F4","88A479","047295","D446E1","78D162","08F8BC","90A25B","7CAB60","44C65D","187EB9","20E874","D03FAA","640BD7","A8913D","0C3B50","748F3C","40F946","B41BB0","58D349","F434F0",
  "B08C75","9C28B3","A07817","5C8730","14D19E","40C711","5C7017","8CEC7B","B881FA","9C760E","94EA32","50F4EB","28C709","507AC5","4C6BE8","8C861E","542B8D","4418FD","005B94","E0897E",
  "64C753","38F9D3","FC183C","90E17B","D81C79","58E6BA","9CE65E","C49880","E0338E","08F69C","50A67F","D461DA","F01898","881908","5C0947","14205E","B841A4","D4909C","E4E0A6","80B03D",
  "E49ADC","ACE4B5","D0D2B0","8C8590","6C96CF","78886D","20EE28","B4F61C","08F4AB","D4DCCD","484BAA","DCA904","6CAB31","4C74BF","989E63","886B6E","5082D5","64B0A6","7C04D0","84FCAC",
  "DC0C5C","70700D","186590","F86214","784F43","404D7F","9C8BA0","CC088D","609AC1","748D08","10DDB1","C01ADA","68FB7E","84A134","0C5101","2CF0A2","B44BD2","DC415F","F45C89","20768F",
  "E8B2AC","E49A79","38CADA","34AB37","18AF61","5CF938","6C72E7","741BB2","CC4463","60FEC5","E425E7","BC926B","101C0C","080007","40D32D","C42C03","9027E4","109ADD","581FAA","88C663",
  "001F5B","002436","00254B","0016CB","0017F2","7C6D62","20C9D0","68967B","84FCFE","E48B7F","008865","BC3BAF","3CE072","38484C","A46706","8C5877","7CF05F","804971","6C3E6D","BC6778",
  "D8D1CB","A8FAD8","B817C2","7C11BE","283737","50EAD6","98D6BB","189EFC","ACCF5C","80006E","848E0C","3C15C2","6C709F","C0F2FB","24E314","80E650","90FD61","087045","A88808","A4C361",
  "2CF0EE","5C97F3","D4F46F","6476BA","34E2FD","04489A","F0F61C","8C2937","B09FBA","0C4DE9","E0F5C6","A0EDCD","5CF5DA","18EE69","649ABE","F099BF","94E96A","AC293A","9CFC01","9C35EB",
  "48437C","34A395","787E61","60F81D","38C986","D03311","507A55","209BCD","F0A35A","608373","84AD8D","74428B","2877F1","88A9B7","ECCED7","AC9085","B89047","909C4A","908C43","3C7D0A",
  "14C88B","EC2651","183EEF","607EC9","64D2C4","DC5285","E88152","908158","D0D23C","78E3DE","60BEC4","F8B1DD","F8665A","A8817E","C41411","CCC95D","34318F","1C9180","4CB910","E0925C",
  "1855E3","E450EB","886440","6070C0","F0C371","941625","34A8EB","A483E7","F4AFE7","AC88FD","DC080F","F8E94E","EC2CE2","40BC60","E83617","9C648B","344262","14D00D","645AED","C0B658",
  "48A91C","50BC96","FC2A9C","A056F3","549963","90DD5D","C48466","347C25","CC2DB7","E42B34","3C2EF9","A04EA7","F0989D","B019C6","3866F0","703EAC","9810E8","C0D012","BCA920","48A195",
  "F80377","DCA4CA","8C8FE9","2C200B","8866A5","001CB3","F07960","A0D795","B8FF61","90C1C6","70A2B3","F40F24","4C57CA","48E9F1","1C9E46","C0CCF8","9C4FDA","8489AD","68DBCA","086698",
  "BC5436","044BED","6C8DC1","0CD746","60A37D","9060F1","B8782E","000502","000A95","00264A","041E64","001124","002241","7CC537","78CA39","18E7F4","70CD60","8C7B9D","D89E3F","B8C75D",
  "0C74C2","403004","842999","74E2F5","E0C97A","68A86D","7CC3A1","7073CB","90840D","E80688","EC852F","00F4B9","5C95AE","9803D8","60C547","685B35","2CB43A","689C70","380F4A","3010E4",
  "A886DD","444C0C","B4F0AB","80929F","9C04EB","5C969D","609217","84B153","E06678","48D705","041552","CC785F","88CB87","F0C1F1","843835","8C006D","A8968A","F41BA1","60D9C7","3CAB8E",
  "F82793","907240","908D6C","B8098A","4C7C5F","68644B","C81EE7","A43135","68D93C","00F76F","C88550","7014A6","985AEB","78D75F","E0B52D","6C94F8","C0CECD","C869CD","A4B805","5CADCF",
  "BC6C21","544E90","ACBC32","7CA1AE","3C22FB","940C98","E8FBE9","38EC0D","E490FD","84AB1A","D06544","D8DC40","805FC5","206980","3C4DBE","48262C","147DDA","C4910C","9860CA","4490BB",
  "34FD6A","443583","E06D17","F0B3EC","F465A6","44F21B","74650C","F4D488","682F67","50ED3C","848C8D","0CE441","B82AA9","7864C0","E81CD8","3C0630","74E1B6","F40E01","1495CE","50DE06",
  "CC660A","FC1D43","B8B2F8","98460A","B85D0A","7C9A1D","103025","5462E2","149D99","C09AD0","94B01F","94F6D6","F82D7C","18810E","608C4A","74B587","FCB6D8","241B7A","8CFE57","C0A600",
  "000393","1C1AC0","40831D","DCD3A2","5C1DD9","88AE07","68FEF7","68EF43","D02B20","2C61F6","D4A33D","F0766F","4098AD","6C4D73","7867D7","B8C111","9CE33F","A8BE27","C0A53E","D4619D",
  "14BD61","7C5049","58404E","D0C5F3","BC9FEF","20AB37","60F445","88E87F","9CF48E","5CF7E6","B853AC","203CAE","A03BE3","4C3275","D83062","B88D12","8C8EF2","90B0ED","04D3CF","B48B19",
  "BCEC5D","28A02B","3871DE","7081EB","606944","0452F3","60FB42","64B9E8","001D4F","002312","D8A25E","000A27","183451","0C771A","286ABA","4CB199","C09F42","D023DB","70DEE2","F0CBA1",
  "182032","403CFC","4860BC","3451C9","406C8F","5855CA","DC2B61","40A6D9","60FACD","003EE1","FC253F","04F7E4","34C059","F0D1A9","705681","14109F","040CCE","54EAA8","28E14C","E4C63D",
  "54E43A","04DB56","AC3C0B","701124","042665","EC3586","78FD94","2CBE08","E8802E","006171","8C7C92","B03495","F437B7","AC7F3E","280B5C","ACFDEC","DC9B9C","54724F","D8CF9C","7C6DF8",
  "04E536","A8BBCF","6C4008","40331A","CCC760","BC4CC4","DC3714","20A2E4","28F076","7C0191","80D605","DC2B2A","082CB6","F84E73","F07807","3CCD36","444ADB","309048","D84C90","24D0DF",
  "6C4A85","28F033","BC0963","E87F95","88C08B","4C7CD9","BCA5A9","20E2A8","A0FBC5","007D60","C40B31","149877","88665A","B0E5F9","40E64B","B4FA48","F02F4B","90FFD6","C0280B","9CEA97",
  "C89BAD","14AE857""A06974","EC6488","E42761","98BEDC","0CB789","9C0567","047975","10327E","30FBB8","44D791","8446FE","D82918","D46BA6","CC0577","D462EA","54BAD6","24166D","940B19",
  "70C7F2","88F56E","C8C2FA","CC64A6","F89A78","88F872","EC5623","18022D","48F8DB","64F81C","807D14","20283E","88108F","F4631F","A49B4F","342EB6","AC9232","8C6D77","14579F","B44326",
  "74C14F","B0EB57","F898EF","58F987","A8F5AC","58BAD4","00BE3B","7CA177","242E02","A4933F","F00FEC","AC075F","104400","B0E17E","E4A7C5","F86EEE","786256","B05508","28A6DB","14A0F8",
  "3C678C","407D0F","68CC6E","D8C771","80D4A5","04B0E7","446A2E","5001D9","487B6B","883FD3","18D276","48FD8E","AC6175","244427","5CA86A","042758","9CE374","DCD916","9C741A","E4A8B6",
  "244C07","54511B","D4612E","745AAA","04FE8D","48AD08","4CFB45","009ACD","7CB15D","88CF98","38F889","D07AB5","B43052","80D09B","1C8E5C","904E2B","2008ED","0034FE","C85195","40CBA8",
  "D46E5C","8853D4","04C06F","202BC1","54A51B","002568","781DBA","00259E","D46AA8","B8BC1B","582AF7","4C8BEF","FC48EF","707BE8","4C1FCC","D4B110","E468A3","3400A3","68A828","BC9C31",
  "E4C2D1","845B12","D4F9A1","0022A1","F03F95","185644","9C69D1","D88ADC","10E953","E04007","7817BE","740AE1","B4A898","0CE4A0","BC1AE4","702F35","6C1632","2C1A01","7422BB","B40931",
  "94E7EA","94E4BA","347146","2CC546","0C839A","E0E0FC","F4B78D","A416E7","68E209","A0DE0F","F487C5","105DDC","DC7385","5455D5","3C306F","80E1BF","482CD0","9408C7","C8CA63","9437F7",
  "903FEA","20AB48","CCD73C","24E9CA","FC73FB","241AE6","E4D373","C0BC9A","006151","BC76C5","5CD89E","8454DF","F0F7E7","90808F","D44F67","B4FF98","107100","14AB02","AC471B","008A55",
  "64A28A","24649F","0C1773","E81E92","888E68","78CF2F","A83B5C","F0FEE7","54211D","04495D","484C29","C4D438","C4E287","9C823F","54F607","F0258E","9C746F","3C9BC6","10A4DA","382028",
  "E47727","28D3EA","A8F266","24456B","483871","E8FD35","ECC5D2","A070B7","78B554","689E6A","282B96","F4FBB8","F89753","5894AE","B03ACE","F84CDA","A0D807","2C780E","34B20A","B00875",
  "847637","FC9435","E02481","5CE883","100177","44A191","4459E3","9835ED","084F0A","A8494D","44004D","18CF24","D89B3B","88403B","FC8743","04885F","C850CE","20DA22","20658E","183D5E",
  "88CEFA","70D313","9C1D36","CCBBFE","E43493","342912","14D169","60F18A","10C172","EC8C9A","B48655","D0D783","501D93","3CCD5D","7C7668","C49F4C","0C704A","B4FBF9","506F77","0C41E9",
  "3CE824","940E6B","5C546D","0C8FFF","54B121","101B54","A80C63","5CC307","28B448","BC3F8F","143004","5004B8","44C346","307496","708A09","F02FA7","18DED7","7C11CB","049FCA","50016B",
  "A47174","F4CB52","B808D7","34A2A2","749D8F","F823B2","E0A3AC","BC7574","20A680","8828B3","DCEE06","14D11F","DC094C","1C6758","24BCF8","A4BA76","48DB50","001882","20F3A3","0C37DC",
  "BC7670","24DBAC","1C1D67","2469A5","EC233D","78F5FD","5C7D5E","90671C","BC25E0","F4E3FB","D02DB3","E8CD2D","84A8E4","0C96BF","60E701","E8088B","643E8C","7C6097","CC53B5","60DE44",
  "105172","08E84F","888603","04F938","AC853D","4846FB","E0247F","00464B","80FB06","6889C1","2CCF58","7CA23E","88A2D7","9C37F4","3C4711","A0DF15","18703B","D89E61","347E00","78B46A",
  "6CEBB6","4CF55B","E83F67","3446EC","6C06D6","DC21E2","FC1BD1","582575","28DEE5","44C7FC","7885F4","F4A4D6","08F458","980D51","00ADD5","B8E3B1","285471","B88E82","DC333D","785773",
  "AC6089","843E92","708CB6","50464A","C4A402","183CB7","A4BDC4","5C9157","3066D0","3CB233","C0FFA8","98B3EF","50F958","345840","5C647A","BC7F7B","F0FAC7","DCEF80","A83512","90F644",
  "6C442A","A47CC9","C40D96","A4AC0F","CCFF90","D4D51B","2491BB","645E10","C8E600","309610","C4278C","7C73EB","E48F1D","94B271","A4178B","B098BC","24016F","983F60","C03FDD","9C7370",
  "C4DE7B","6C1A75","6C7637","F85329","8815C5","A4AAFE","F83B7E","7040FF","34D693","C0F6EC","CC208C","389052","C0E018","5CE747","A8FFBA","8C0FC9","304E1B","E8D765","04F03E","78E22C",
  "C0D026","307C4A","D85982","48B25D","C0D46B","9C9567","A47B1A","04BA1C","7C3D2B","FC4DA6","B414E6","AC9929","E8A660","082FE9","984874","1CA681","C8BFFE","082E36","30A2C2","283334",
  "ACB3B5","08318B","3C9D56","70FD45","446747","E419C1","E4FDA1","FCBCD1","7460FA","8CFD18","C40683","94D00D","1C20DB","D0C65B","24DA33","FCAB90","E0CC7A","F47960","4455B1","70192F",
  "DC16B2","24FB65","0CB527","347916","D016B4","D0EFC1","485702","9C713A","2C97B1","F8C39E","1409DC","60DEF3","EC8914","B89436","58D759","804126","ACF970","74D21D","602E20","E472E2",
  "044F4C","1C151F","DCC64B","043389","2C55D3","C81451","F0C850","C80CC8","0425C5","3CFA43","145F94","F09838","F04347","9CB2B2","A8C83A","483C0C","20F17C","346AC2","84AD58","58605F",
  "C4473F","2400BA","24DF6A","7C7D3D","4482E5","E84DD0","0C45BA","B05B67","CCA223","786A89","14B968","5CF96A","50A72B","0CD6BD","00F81C","087A4C","ACE215","346BD3","70723C","ACE87B",
  "F83DFF","285FDB","404D8E","4C5499","F49FF3","240995","84DBAC","94772B","D440F0","04021F","200BC7","F84ABF","78D752","104780","548998","70A8E3","F8E811","94049C","688F84","30D17E",
  "E03676","EC388F","D03E5C","A4DCBE","D494E8","F8BF09","5CB43E","249EAB","AC8D34","246F8C","1C1386","BC2EF6","4455C4","14A32F","04D3B5","00BB1C","E884C6","642CAC","A82BCD","48DC2D",
  "D005E4","30AAE4","10C3AB","2811EC","38EB47","147740","18D98F","189E2C","5471DD","884033","E0D462","909838","0831A4","A8E978","F82F65","942533","F09BB8","8C5EBD","2CA042","ECC01B",
  "9844CE","C083C9","982FF8","40DCA5","30C50F","2868D2","C868DE","D00DF7","4805E2","C4D738","C0F6C2","04C1D8","C8BC9C","B0FEE5","58D061","642315","A4C74B","BC9789","684571","8493A0",
  "9C8E9C","4014AD","E04BA6","C8B6D3","089356","6C146E","44E968","647924","D8CC98","BC9930","6CE874","C469F0","AC3328","E02E3F","BC9A53","DC2727","F042F5","5CBD9A","14A3B4","E86DE9",
  "144658","58BE72","108FFE","D847BB","C833E5","98AD1D","00682B","981A35","60A751","182A57","F83E95","481258","CC3296","449BC1","B02491","98751A","B48901","048C9A","EC3CBB","BCB0E7",
  "5434EF","ACE342","9017C8","E00084","F41D6B","2841C6","B4F58E","243154","2C58E8","F063F9","7CC385","30A1FA","3412F9","BCE265","4CD1A1","88BFE4","340A98","646D6C","C4B8B4","80B575",
  "A4BE2B","A87D12","4CD0CB","505DAC","B4CD27","DC729B","909497","0CC6CC","785860","E8ABF3","6CB749","989C57","E86819","3C7843","5C0979","E4FB5D","8C2505","5425EA","C894BB","10B1F8",
  "38BC01","341E6B","886639","884477","149D09","707990","4CF95D","8421F1","005A13","2C9D1E","68A0F6","446EE5","34B354","50680A","FC3F7C","384C4F","900325","98E7F5","7C1CF1","78F557",
  "E02861","D0D04B","480031","2CAB00","A8CA7B","A08D16","EC4D47","F4559C","80B686","10C61F","CC96A0","F80113","A49947","C8D15E","C07009","8038BC","C4072F","F48E92","00664B","9CC172",
  "247F3C","581F28","ECCB30","F4DCF9","308730","241FA0","18C58A","7054F5","DCD2FC","9017AC","34CDBE","D8490B","9C28EF","F898B9","FCE33C","C4447D","30E98E","ACBD70","C0B5CD","4C5077",
  "30FD65","B0735D","5C78F8","B827C5","78C5F8","B4B055","048C16","B0CCFE","540DF9","006619","447654","7CD9A0","F033E5","B4F18C","E48326","40B6E7","D0B45D","8836CF","A4C54E","D4BBE6",
  "B04502","1C1FF1","14DE39","9016BA","60AAEF","D0F3F5","D44649","9400B0","2848E7","E43EC6","38881E","E4268B","58F2FC","E8136E","4CAE13","DCD444","A446B4","A83759","50F7ED","0C31DC",
  "245F9F","CCB0A8","502873","F82E3F","90A5AF","D8A491","681324","A8C092","7845B3","20DCFD","FC65B3","109D7A","88892F","28E5B0","9CB2E8","14563A","7090B7","3CA37E","48EF61","78F09B",
  "E07726","74E9BF","D8109F","3C5447","006B6F","58AE2B","6CD704","14230A","58AEA8","64D7C0","946010","6413AB","003DE1","7C1B93","DC2D3C","E00CE5","2841EC","7C004D","8C3446","E0E37C",
  "E8EA4D","3CFFD8","4C617E","C0DCD7","3037B3","385247","684AAE","60D755","A8C252","A04147","1CAECB","044A6C","38FB14","F0E4A2","24A52C","7C942A","1CB796","3847BC","549209","745909",
  "68A03E","B8C385","C8A776","A400E2","483FE9","143CC3","A8E544","1C7F2C","88BCC1","8C426D","1C599B","806933","DC9088","902BD2","40EEDD","AC751D","289E97","8C15C7","60FA9D","DC9914",
  "304596","C0F4E6","F4BF80","E0191D","3C15FB","881196","E40EEE","0C2C54","047970","A057E3","BC3D85","2054FA","38378B","002EC7","488EEF","5C0339","84A9C4","A0086F","D06F82","A0F479",
  "844765","C4FF1F","F87588","F44C7F","A0A33B","D0FF98","B0E5ED","C486E9","C0BFC0","A08CF8","14A51A","047503","9C7DA3","A4C64F","8C0D76","84BE52","849FB5","A4CAA0","C88D83","C81FBE",
  "203DB2","48D539","D4A148","D065CA","8CEBC6","B08900","CCCC81","08C021","600810","48435A","C4F081","801382","94FE22","608334","E47E66","94DBDA","9C52F8","BC620E","74A528","E09796",
  "ACCF85","00E0FC","6416F0","88E3AB","C40528","3CDFBD","509F27","80717A","5C4CA9","F4C714","286ED4","001E10","5439DF","283CE4","587F66","64A651","086361","8C34FD","0819A6","3CF808",
  "486276","B41513","AC4E91","283152","74882A","4CB16C","04BD70","E435C8","E8BDD1","5CB395","30F335","74A063","F4E5F2","541310","8CE5EF","54F294","484C86","A01C8D","F4DEAF","60123C",
  "F4A59D","E0F442","F0C42F","C0B47D","C467D1","C8C465","1C4363","8C5AC1","A85AE0","A4B61E","2864B0","04F169","5021EC","8C683A","B46E08","94E9EE","28E34E","F8AF05","90173F","607ECD",
  "0094EC","74452D","80CFA2","F05501","1413FB","B0761B","145120","C0D193","7804E3","A43B0E","2481C7","FC862A","1C3D2F","EC753E","54D9C6","308AF7","D8EF42","80CC12","18AA0F","00E406",
  "44227C","CCB182","C42B44","400634","04E795","C41688","64B0E8","30A998","3898E9","F4C7AA","005043","000CE7","000A00","48B02D","00044B","88124E","00A0C6","649C81","8CFDF0","10DCB69",
  "D0D003","8CB84A","7C8956","88299C","8C79F5","D003DF","FC039F","A4D990","3C576C","08C5E1","E4B021","C048E6","CC6EA4","A816D0","A46CF1","08AED6","9CE063","D03169","149F3C","7C6456",
  "389AF6","E0AA96","507705","C8D7B0","9097F3","7C1C68","C087EB","3096FB","4827EA","7C787E","28395E","8CF5A3","D47AE2","D8E0E1","F83F51","60A4D0","008701","5C9960","101DC0","68EBAE",
  "444E1A","78471D","A07591","0CDFA4","002637","002119","F4D9FB","3C6200","5CA39D","90187C","50CCF8","50B7C3","1C5A3E","A02195","E47CF9","4844F7","001377","002454","E81132","C06599",
  "BC79AD","4C3C16","0073E0","0017D5","001E7D","001DF6","F008F1","58C38B","00E3B2","301966","F0E77E","94350A","001D25","343111","08FD0E","041BBA","889B39","E432CB","BC8CCD","D022BE",
  "EC9BF3","F409D8","10D542","A0821F","F06BCA","AC3613","4849C7","849866","9476B7","4C6641","B8BBAF","60C5AD","CCB11A","E4FAED","288335","DCCF96","A80600","F05A09","503275","08FC88",
  "24F5AA","988389","84A466","C4576E","508569","F8D0BD","78595E","0C1420","94B10A","3CBBFD","A48431","A0B4A5","E4F8EF","E8B4C8","D087E2","F05B7B","B047BF","7C0BC6","205531","5440AD",
  "804E81","FC8F90","9CD35B","A89FBA","30D587","D059E4","14A364","002538","0C2FB0","70CE8C","F4FEFB","B41A1D","30AB6A","60684E","8020FD","B4CE40","04BDBF","BC7ABF","54219D","98B8BC",
  "184E16","C03D03","C418E9","1CE57F","18CE94","783716","00FA21","7C2302","D49DC0","489DD1","B06FE0","60D0A9","007C2D","007204","BCA58B","80CEB9","00C3F4","FC643A","A8515B","88BD45",
  "54FCF0","306A85","4CDD31","D0B128","BC5451","2C4053","ACAFB9","503DA1","3C0518","900628","38AA3C","EC107B","1C232C","0021D1","001FCC","60A10A","8C71F8","CC051B","8C7712","9463D1",
  "0021D2","5C497D","7825AD","ECE09B","78D6F0","BC20A4","08D42B","789ED0","B0C4E7","A00798","001FCD","38ECE4","945103","002490","0023D7","549B12","FCA13E","24C696","94D771","E84E84",
  "001632","E4E0C5","C81479","1CAF05","0016DB","001EE2","20D5BF","5CE8EB","C0BDD1","B479A7","B0DF3A","805719","34BE00","78521A","205EF7","141F78","B47443","F877B8","182195","44783E",
  "14BB6E","28CC01","6CF373","9C3AAF","781FDB","4CA56D","B86CE8","0CB319","183F47","B46293","50A4C8","1867B0","6C8336","ACEE9E","B857D8","AC5A14","08ECA9","7840E4","E09971","10D38A",
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
void loop()
{   
  if (interruptCounter > 0) {
    interruptCounter--;
    minutes_acc++;
    totalInterruptCounter++;
    shtc3.getEvent(&humidity, &temp); // populate temp object with fresh data
  
     if(minutes_acc%15 == 0 and totalInterruptCounter != 0){
        detection_wifi();
        format_message();  
    }
  }
}

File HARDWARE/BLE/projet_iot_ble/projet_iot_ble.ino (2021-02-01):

#define WIFI_SSID "A83S48_US"
#define WIFI_PASSWORD "pipicaca123"
#define POST_URL "http://192.168.43.186:3000/"
#define SCAN_TIME 10     // seconds
#define WAIT_WIFI_LOOP 5 // around 4 seconds for 1 loop
#define SLEEP_TIME 1   // seconds

#include <Arduino.h>
#include <sstream>

#include <BLEDevice.h>
#include <BLEUtils.h>
#include <BLEScan.h>
#include <BLEAdvertisedDevice.h>

#include <WiFi.h>
#include <WiFiMulti.h>
#include <esp_wifi.h>

#include <HTTPClient.h>

#include "soc/soc.h"
#include "soc/rtc_cntl_reg.h"

WiFiMulti wifiMulti;
std::stringstream ss;
bool data_sent = false;
int wait_wifi_counter = 0;
byte mac[6];

class MyAdvertisedDeviceCallbacks : public BLEAdvertisedDeviceCallbacks
{
  void onResult(BLEAdvertisedDevice advertisedDevice)
  {
    log_i("Advertised Device: %s \n", advertisedDevice.toString().c_str());
  }
};

void setup()
{
  log_i("ESP32 BLE Scanner");

  // disable brownout detector to maximize battery life
  log_i("disable brownout detector");
  WRITE_PERI_REG(RTC_CNTL_BROWN_OUT_REG, 0);

  log_i("BLEDevice::init()");
  BLEDevice::init("");

  // put your main code here, to run repeatedly:
  BLEScan *pBLEScan = BLEDevice::getScan(); //create new scan
  pBLEScan->setAdvertisedDeviceCallbacks(new MyAdvertisedDeviceCallbacks());
  pBLEScan->setActiveScan(true); //active scan uses more power, but get results faster
  pBLEScan->setInterval(0x50);
  pBLEScan->setWindow(0x30);

  log_i("Start BLE scan for %d seconds...\n", SCAN_TIME);

  BLEScanResults foundDevices = pBLEScan->start(SCAN_TIME);
  int count = foundDevices.getCount();
  ss << "[";
  for (int i = 0; i < count; i++)
  {
    if (i > 0)
    {
      ss << ",";
    }
    BLEAdvertisedDevice d = foundDevices.getDevice(i);
    ss << "{\"Address\":\"" << d.getAddress().toString() << "\",\"Rssi\":" << d.getRSSI();

    if (d.haveName())
    {
      ss << ",\"Name\":\"" << d.getName() << "\"";
    }

    if (d.haveAppearance())
    {
      ss << ",\"Appearance\":" << d.getAppearance();
    }

    if (d.haveManufacturerData())
    {
      std::string md = d.getManufacturerData();
      uint8_t *mdp = (uint8_t *)d.getManufacturerData().data();
      char *pHex = BLEUtils::buildHexData(nullptr, mdp, md.length());
      ss << ",\"ManufacturerData\":\"" << pHex << "\"";
      free(pHex);
    }

    if (d.haveServiceUUID())
    {
      ss << ",\"ServiceUUID\":\"" << d.getServiceUUID().toString() << "\"";
    }

    if (d.haveTXPower())
    {
      ss << ",\"TxPower\":" << (int)d.getTXPower();
    }

    ss << "}";
  }
  ss << "]";

  log_i("Scan done!");

  wifiMulti.addAP(WIFI_SSID, WIFI_PASSWORD);
  WiFi.macAddress(mac);
  Serial.print("MAC: ");
  Serial.print(mac[5],HEX);
  Serial.print(":");
  Serial.print(mac[4],HEX);
  Serial.print(":");
  Serial.print(mac[3],HEX);
  Serial.print(":");
  Serial.print(mac[2],HEX);
  Serial.print(":");
  Serial.print(mac[1],HEX);
  Serial.print(":");
  Serial.println(mac[0],HEX);
}

void loop()
{
  // wait for WiFi connection
  if ((wifiMulti.run() == WL_CONNECTED))
  {
    log_i("WiFi Connected");

    // HTTP POST BLE list
    HTTPClient http;

    log_i("[HTTP] Payload:\n%s", ss.str().c_str());
    log_i("[HTTP] Begin...");

    // configure traged server and url
    http.begin(POST_URL);

    // start connection and send HTTP header
    int httpCode = http.POST(ss.str().c_str());

    // httpCode will be negative on error
    if (httpCode > 0)
    {
      // HTTP header has been send and Server response header has been handled
      log_i("[HTTP] GET... code: %d\n", httpCode);

      // file found at server
      if (httpCode == HTTP_CODE_OK)
      {
        log_i("[HTTP] Response:\n%s", http.getString());
      }
    }
    else
    {
      log_i("[HTTP] GET... failed, error: %s\n", http.errorToString(httpCode).c_str());
    }

    http.end();
    data_sent = true;
  }

  // wait WiFi connected
  if (data_sent || (wait_wifi_counter > WAIT_WIFI_LOOP))
  {
    esp_sleep_enable_timer_wakeup(SLEEP_TIME * 1000000); // translate second to micro second

    log_i("Enter deep sleep for %d seconds...\n", SLEEP_TIME);

    esp_wifi_stop();
    esp_deep_sleep_start();
  }
  else
  {
    wait_wifi_counter++;

    log_i("Waiting count: %d\n", wait_wifi_counter);
  }
}

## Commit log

2021-02-01 menage dans les fichiers
2021-02-01 code avec tous les capteurs à tester
2021-02-03 base de donnees
2021-02-03 modif base de donnees
2021-02-03 Ajout temperature
2021-02-08 liste adresses MAc a restreindre
    [MAC_alcatel.CSV, MAC_allwinner.CSV, MAC_apple.CSV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]
2021-02-08 filtre temperature
2021-02-10 noms des animaux adéquats filtres
2021-02-10 creation tableau mac
    [combined.csv]
2021-02-10 modifs selection animal temperatures
2021-02-11 correction temperatures
2021-02-11 code acccelero seuil de mouvement sur 5 cm
2021-02-15 exemple de trames
2021-02-15 Schema complet avec accelerometre
2021-02-15 ajout post temperature
2021-02-15 insertion température base de données
2021-02-15 insertion température base de données 2
2021-02-15 definition d'un fichier python test de requete google api
2021-02-16 code Accelero_seuil version interruption
2021-02-16 Gestion des interruptions pour temp & acc
2021-02-17 Correction interruption temp
2021-02-17 key de melissa sécurisée
2021-02-17 ajout accelero a temperature
2021-02-17 Ajout de toutes les nouvelles modifs
2021-02-17 creation small-rest pour json version POST device
2021-02-18 nettoyage de rest
2021-02-18 changing case 1 strcat
2021-02-19 Réorganisation + ajout schémas + prez
    [MAC_alcatel.CSV, MAC_allwinner.CSV, MAC_apple.CSV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]
2021-02-19 Suppression doublon
    [MAC_alcatel.CSV, MAC_allwinner.CSV, MAC_apple.CSV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]
2021-02-20 Plan PCB alim
2021-02-20 add PCB
2021-02-20 Correction orientation composants PCB
2021-02-21 Ajout README.md dans HARDWARE/CODE et maj des fichiers
